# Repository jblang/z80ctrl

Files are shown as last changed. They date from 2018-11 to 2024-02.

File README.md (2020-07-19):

# z80ctrl

z80ctrl is an AVR-based bootloader, debugger, and I/O device for a Z80 retrocomputer with the following features:

- Plug-in module for [RC2014](https://rc2014.co.uk/) retrocomputer replaces the clock, serial, ROM, and CF boards
- Runs CP/M software directly from FAT32-formatted SD Card
- Boots unmodified disk images from the [AltairZ80](https://schorn.ch/altair.html) emulator
- Monitor with file management, memory inspector, and built-in Z80 disassembler
- Single-step debugging, breakpoints, and watchpoints to trace Z80 bus activity in real-time
- Expandable SPI bus allows bridging other SPI peripherals to the Z80
- Flexible MIT-licensed firmware can be the basis of your own SBC or breadboard computer

IMAGE ALT TEXT HERE (https://www.youtube.com/watch?v=sVV1PYWX18A)

## Documentation

Much of the information that was previously here has been moved to separate wiki pages:

- [Board Assembly Instructions](https://github.com/jblang/z80ctrl/wiki/Board-Assembly-Instructions)
- [Monitor User Guide](https://github.com/jblang/z80ctrl/wiki/Monitor-User-Guide)
- [Known Issues](https://github.com/jblang/z80ctrl/wiki/Known-Issues)
- [Hardware Design Notes](https://github.com/jblang/z80ctrl/wiki/Hardware-Design-Notes)
- [Software Design Notes](https://github.com/jblang/z80ctrl/wiki/Software-Design-Notes)
- [IO Expander Board](https://github.com/jblang/z80ctrl/wiki/IO-Expander-Board)
- Check the [Wiki Index](https://github.com/jblang/z80ctrl/wiki) for other topics.

## Off-Site Resources

- [Hackaday Project Page](https://hackaday.io/project/158338-z80ctrl) with blog articles about various features.
- [YouTube Playlist](https://www.youtube.com/watch?v=M8EIAxMpA-o&list=PLwP_dSEH4Oi_jAljWQ1H-TBiBL34LqYYm)
- [RC2014 Google Group](https://groups.google.com/forum/#!forum/rc2014-z80). Search for z80ctrl to find previous discussion threads.
- [retro-comp Google Group](https://groups.google.com/g/retro-comp)

## License

Copyright 2018-2020 J.B. Langston

Permission is hereby granted, free of charge, to any person obtaining a copy of this software and associated documentation files (the "Software"), to deal in the Software without restriction, including without limitation the rights to use, copy, modify, merge, publish, distribute, sublicense, and/or sell copies of the Software, and to permit persons to whom the Software is furnished to do so, subject to the following conditions:

The above copyright notice and this permission notice shall be included in all copies or substantial portions of the Software.

THE SOFTWARE IS PROVIDED "AS IS", WITHOUT WARRANTY OF ANY KIND, EXPRESS OR IMPLIED, INCLUDING BUT NOT LIMITED TO THE WARRANTIES OF MERCHANTABILITY, FITNESS FOR A PARTICULAR PURPOSE AND NONINFRINGEMENT. IN NO EVENT SHALL THE AUTHORS OR COPYRIGHT HOLDERS BE LIABLE FOR ANY CLAIM, DAMAGES OR OTHER LIABILITY, WHETHER IN AN ACTION OF CONTRACT, TORT OR OTHERWISE, ARISING FROM, OUT OF OR IN CONNECTION WITH THE SOFTWARE OR THE USE OR OTHER DEALINGS IN THE SOFTWARE.

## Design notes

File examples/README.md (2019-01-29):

# z80ctrl Example Programs

These are some example programs that demonstrate features of the z80ctrl and the I/O expander add-on card.

## Assembling

I have tried to stick to a common subset of assembler features that will work with any of the following cross-assemblers:

- [Sjasm](http://www.xl2s.tk/): Windows binaries available for download.  Compiles on Linux using sources on [Github](https://github.com/Konamiman/Sjasm).
- [SjasmPlus](https://sourceforge.net/projects/sjasmplus/):  Windows binaries available for download.  Compiles on Linux using sources on [Github](https://github.com/sjasmplus/sjasmplus).
- [z80asm](https://www.nongnu.org/z80asm/): Binaries available in the Debian repository. Mac binaries on [Homebrew](https://brew.sh/). Compiles on Windows.
- [z88dk](https://github.com/z88dk/z88dk)'s z80asm (not to be confused with above). Windows and Mac binaries available for download. Compiles on Linux.
- [pasmo](http://pasmo.speccy.org/): Windows and Mac binaries available for download. Binaries available in the Debain repository.

My preferred assembler is sjasm. I try to maintain compatibility with all of the above, but may not always test every change against the others.  If you have trouble assembling with any of the above, please try sjasm, and file a bug to let me know about the problem.

## About the Programs

- `graphclk.bas`: MSX-BASIC program draws a graphical clock on TMS9918A with time read from RTC.
- `hello.asm`: Simple hello world assembly program that uses the Altair UART emulation.
- `ioxblink.bas` MBASIC program that blinks an LED using the I/O expander.
- `lcd.bas`: MBASIC program that prompts for a string and prints it on an LCD hooked up to the I/O expander.
- `lcdclock.asm`: Assembly program that reads date/time from RTC and displays it on an LCD hooked up to the I/O expander.
- `rtc.bas`: MBASIC program that reads the date/time from RTC and prints it on the console.
- `z80ops.asm`: Assembly program with all Z80 opcodes, for testing disassembler.

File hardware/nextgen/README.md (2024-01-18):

## z80ctrl NG

**Important: This design has not yet been tested.  Manufacture at your own risk.**

This is a new design for z80ctrl using the [Microchip AVR128DB64](https://www.microchip.com/en-us/product/avr128db64) microcontroller. 

This next-gen AVR has several advantages over the ATmega1284P used in the original design:

- It's a 64-pin part with more than enough I/O to interface with the RC2014 bus without an I/O expander. This will allow much faster data transfers since all signals are accessed in parallel rather than serially.
- It has built-in configurable logic used to assert the wait signal on I/O requests without external glue logic.
- It has multi-voltage I/O where one port can run at 3.3V to interface the SD card and other peripherals directly without level shifters.
- It has UPDI single-wire programming and debug interface, so it's possible to actually use the debugger in MPLAB X with a PicKit, without sacrificing too many pins to JTAG. UPDI also allows the part to be programmed directly from the USB to serial converter without a bootloader.
- The TQFP package leaves enough space to incorporate 512KB of RAM with optional bank switching and an RTC on the same board.
- The one disadvantage is that it's a fine-pitched surface mount part, but now that PCB manufacturers offer board assembly service, it is possible to order a board with the surface mount components pre-populated.

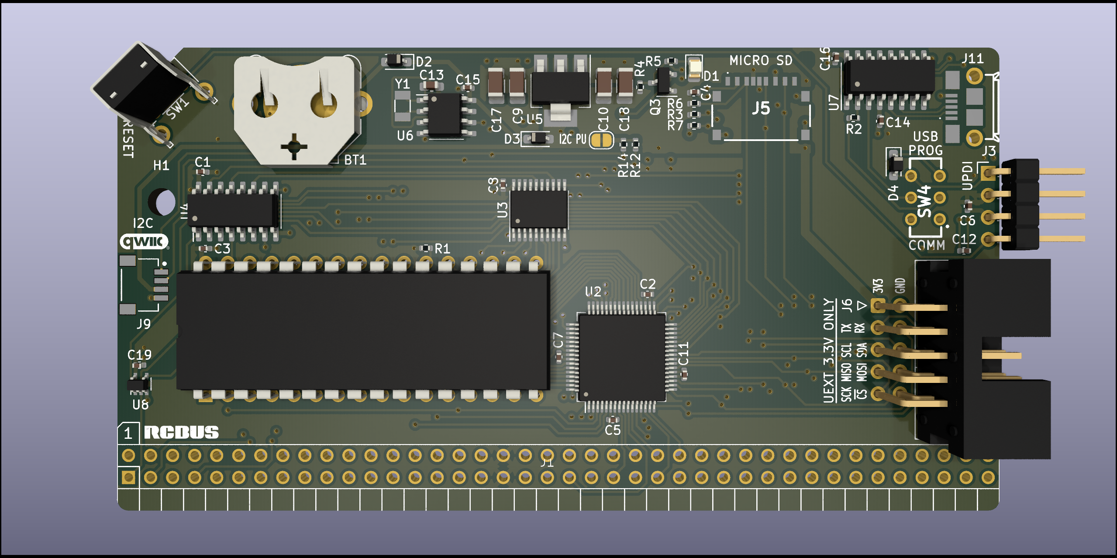
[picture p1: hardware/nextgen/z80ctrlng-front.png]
Front Render


### RAM

This board combines features of the original z80ctrl board plus the RAM and RTC from the companion CPU/RAM/RTC board. The CPU remains on a separate board so that z80ctrl can be used with different CPUs.  

The RAM uses the same bank switching scheme as the original board, with two 32K windows into 512K of RAM:
- The active banks for the upper and lower windows are stored in the upper and lower nybbles of a 74HCT574 8-bit register.  
- A 74HCT257 multiplexer selects between the two windows based on state of A15.  
- Bank switching on this board can be disabled via the slide switch, in which case A15 is connected directly to the SRAM and the output of the 74HCT257 is disabled.  
- A16-A18 are connected directly to the bus, so with bank switching disabled, a CPU with more address lines can be used. 
- The AVR is connected to A16-A18 directly as well so it can work with all 512KB of RAM in either mode.
- Instead of using a 74HCT138 decoder to bank register, it is controlled directly by the AVR. The AVR will listen on a configurable I/O port for bank changes from the CPU and update the flip-flop as needed.

The RAM and bank logic chips are still DIPs to keep the retro vibe, and for practical reasons as well:
- It should still be possible to use z80ctrl for SBCs like the SC126, which already has RAM and ROM, by leaving the RAM on the z80ctrl unpopulated.
- Choosing not to populate the RAM and logic chips allows using the z80ctrl as a stand-alone AVR dev board.
  - Without these chips populated, all the pins used for A0-A18 and D0-D7, and the Z80 control singals can used as GPIO.
  - The passive RCBus backplane can be used to connect non-retro components over the bus.

### MicroSD Card

The board incorporates a MicroSD card holder that the AVR controls over SPI on its 3.3V port.

### RTC

The board includes an RTC for accurate timestamps on the files stored on the SD card:

- The chip used is an [NXP PCF8563T](https://www.nxp.com/part/PCF8563T) I2C RTC. It is backed up by a CR1216 coin cell.
- The bus can be shared with additional I2C peripherals as long as they do not use the same address as the RTC.

### USB Adapter

An on-board [CH340C](https://cdn.sparkfun.com/assets/9/3/0/2/e/ch3402CDS.pdf) USB-to-Serial adapter allows connecting the z80ctrl directly to a host computer over a MicroUSB cable, without any external USB-to-Serial converter required.

Using the PROG EN slide switch, it's also possible to enable programming of the chip via UPDI without a bootloader installed using the same USB connection used for serial communication.

### UEXT Bus

- The 3-volt SPI, I2C, and UART signals are exposed on the [UEXT header](https://www.olimex.com/Products/Modules/UEXT/). This allows it to interface with many different 3V peripherals using I2C, UART, or SPI. 
- Olimex sells many modules using the UEXT connector. For example, a $4 [ESP8266 module](https://www.olimex.com/Products/IoT/ESP8266/MOD-WIFI-ESP8266/open-source-hardware) will allow the z80ctrl to access the internet over its UART using the [ESP AT](https://github.com/espressif/esp-at) firmware.
- The AVR can expose an parallel interface to peripherals over I/O requests on the RCbus.

### Optional RCBus Connections

- The second 5V UART can be connected or disconnected from RX1 or RX2 and TX1 or TX2 signals on the RCbus using jumpers on the serial header.
- 3.3V SPI, I2C, and UART signals can be optionally exported onto the D8-D15 pins by creating a solder bridge on the corresponding surface mount jumpers.

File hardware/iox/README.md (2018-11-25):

[See Wiki](https://github.com/jblang/z80ctrl/wiki/IO-Expander-Board)

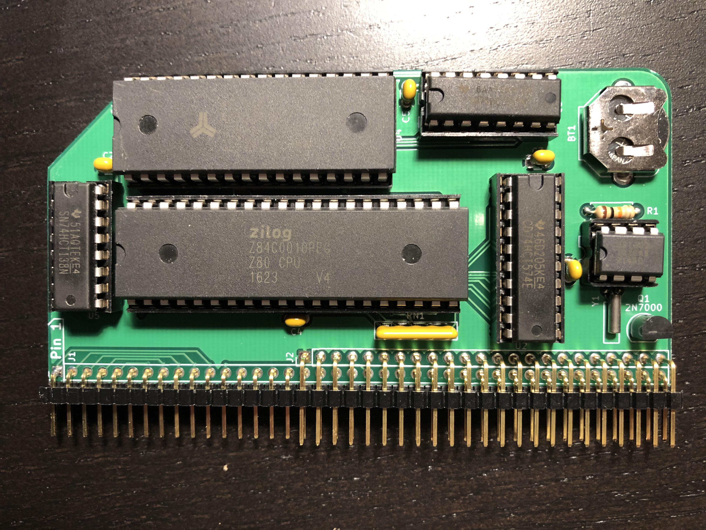
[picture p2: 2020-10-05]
hardware/z80ram/board.jpg

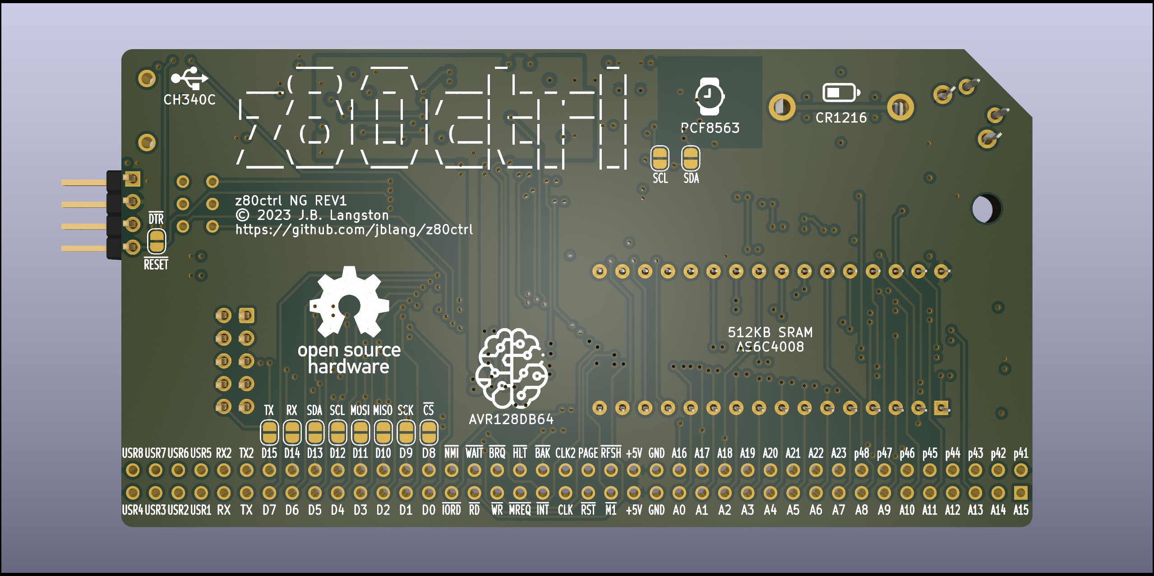
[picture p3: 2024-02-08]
hardware/nextgen/z80ctrlng-back.png

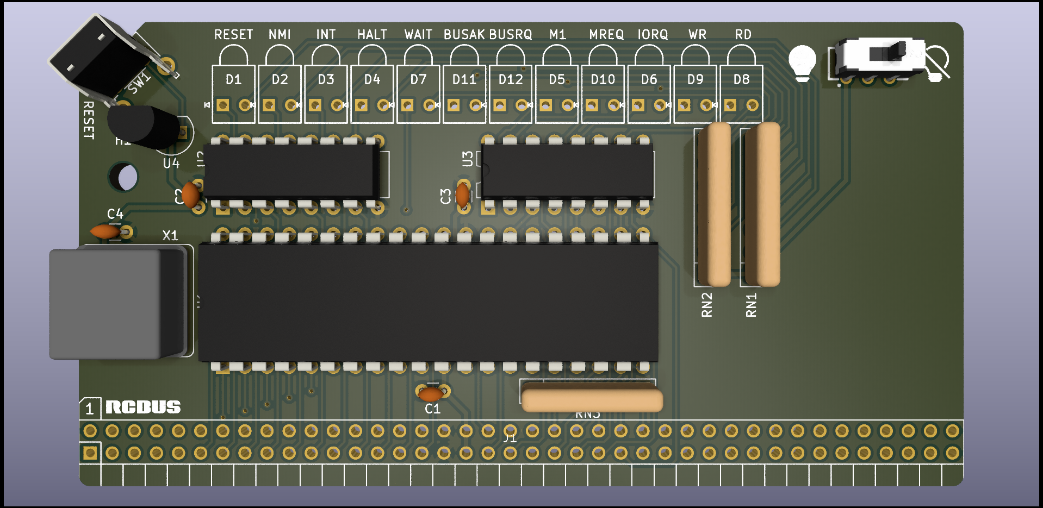
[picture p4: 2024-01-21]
hardware/z80blinken/z80blinken-front.png

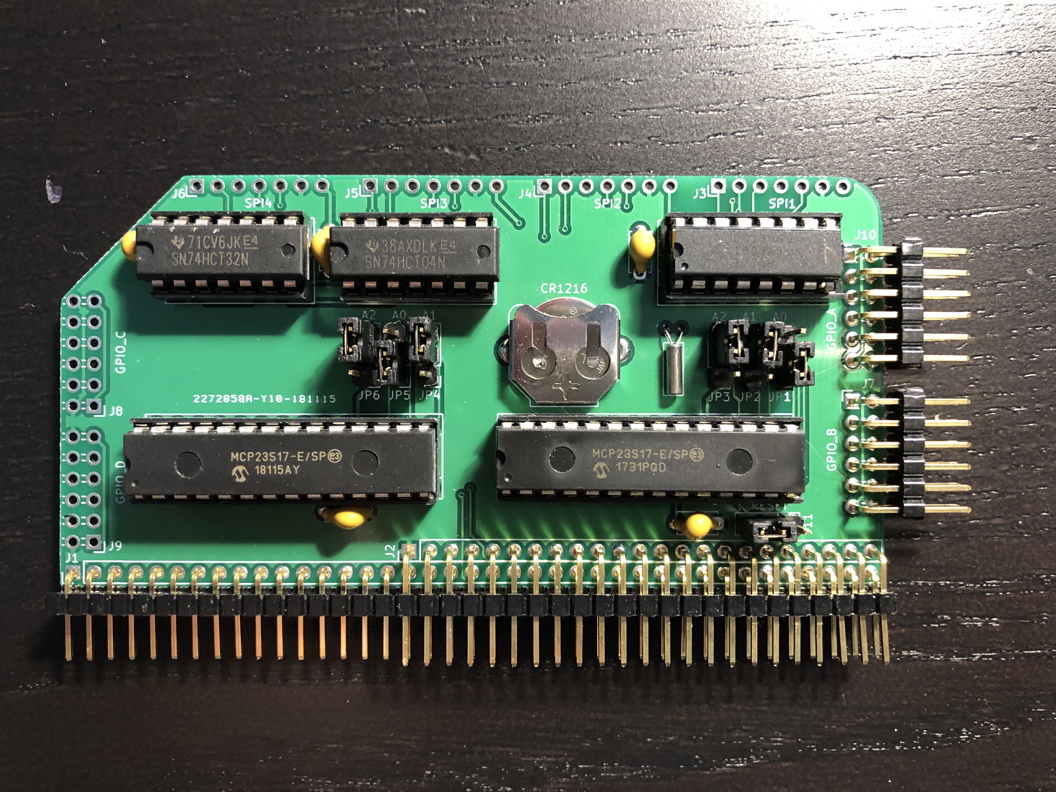
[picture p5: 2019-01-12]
hardware/iox/board.jpg

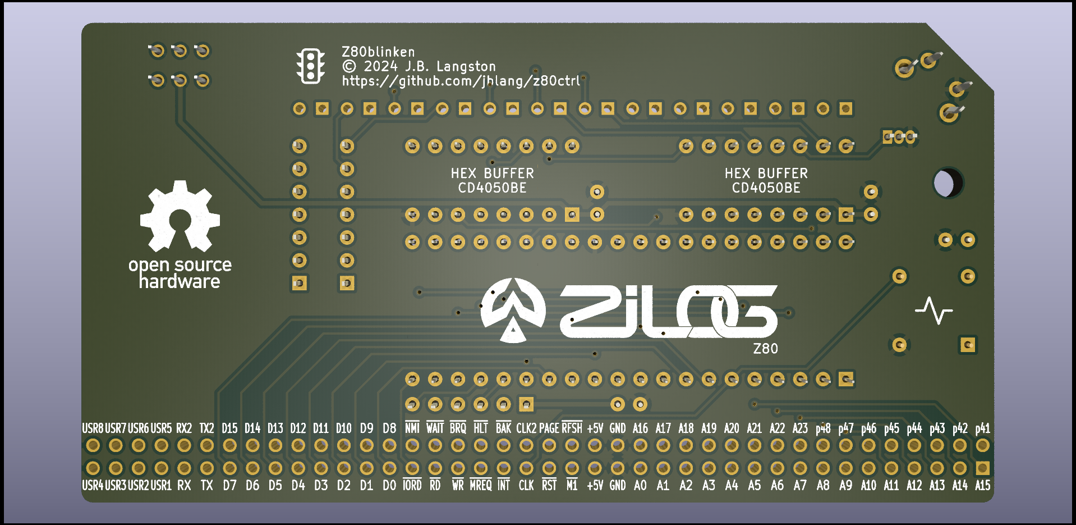
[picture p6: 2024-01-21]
hardware/z80blinken/z80blinken-back.png

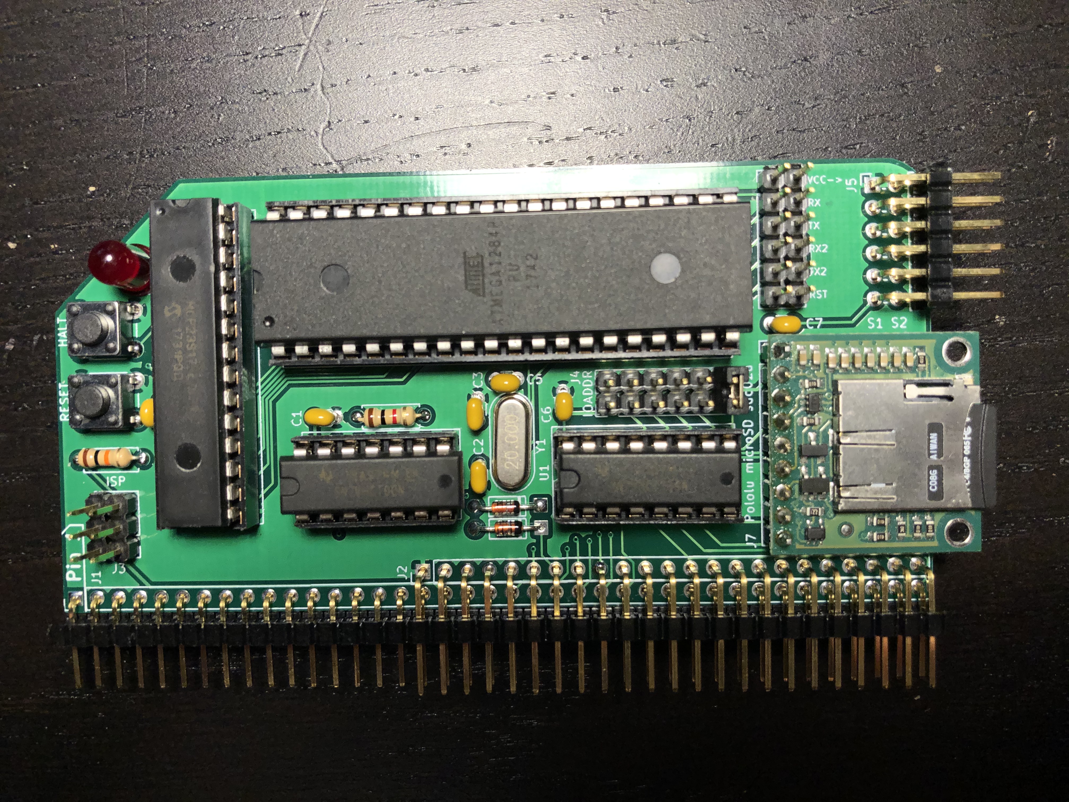
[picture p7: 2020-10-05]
board.jpg

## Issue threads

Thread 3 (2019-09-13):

Problem loading hello.hex

tmator, 2019-09-13:
Hi,

i'm trying to load hello.hex but it's not working, i got :

z80ctrl:/>loadhex hello.hex
loading from hello.hex
bus master request timed out
loaded 45 bytes total from 0100-012c

Any idea ?

Regards.

tmator, 2019-09-13:
And i'm using SC114 motherboard, not RC2014

tmator, 2019-09-13:
Ok, need enchanced bus ! sorry

tmator, 2019-09-13:
Error still here with after connexting nmi, halt, busak, wait, busrq and refsh (SC114 dont have enhanced bus), any idea ?

jblang, 2020-04-23:
I'm sorry, I hadn't worked on z80ctrl for a while and I didn't see that you submitted it. Did you ever figure it out?

I would suggest using a logic analyzer or oscilloscope to see if the busrq and busak lines are actually going low as expected.  Check the busrq signal on the CPU board and the busak signal on the z80ctrl board to make sure the signals are getting from one board to another.   Also make sure that the clock signal is getting to the Z80 from the z80ctrl, and make sure you don't have any other clock sources on the bus.  Make sure that the CLK/WAIT jumper is in the CLK position. A multimeter might do in a pinch but the signals are usually too fast for it to detect so you'd need to edit the code and put in a delay in the correct spots. Some multimeters also have a frequency measurement that you could use to check the clock.

If you're not getting the appropriate signals, check that there are no shorts that are pulling the line up. Visually check for solder bridges and check for continuity between adjacent pins on the bus connector and chips.

jblang, 2020-06-13:
Closing this since I never heard back from you.

Closed 2020-06-13.

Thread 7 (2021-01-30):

where is the J9  description in REV4 and REV6 ?

wenij, 2021-01-30:
I check the "Board Assembly instruction/Jumper configuration" in wiki. And in REV6, it say "J9 (CLK/WAIT) jumper ... ", but I can't find the J9 in the PCB or schematic. Where can I find it?

jblang, 2021-02-04:
There is no CLK/WAIT jumper in REV6.  On REV4 it should always be set to CLK

jblang, 2021-02-04:
It was a copy/paste error that it was listed under REV6. I removed it.

Closed 2021-02-04.

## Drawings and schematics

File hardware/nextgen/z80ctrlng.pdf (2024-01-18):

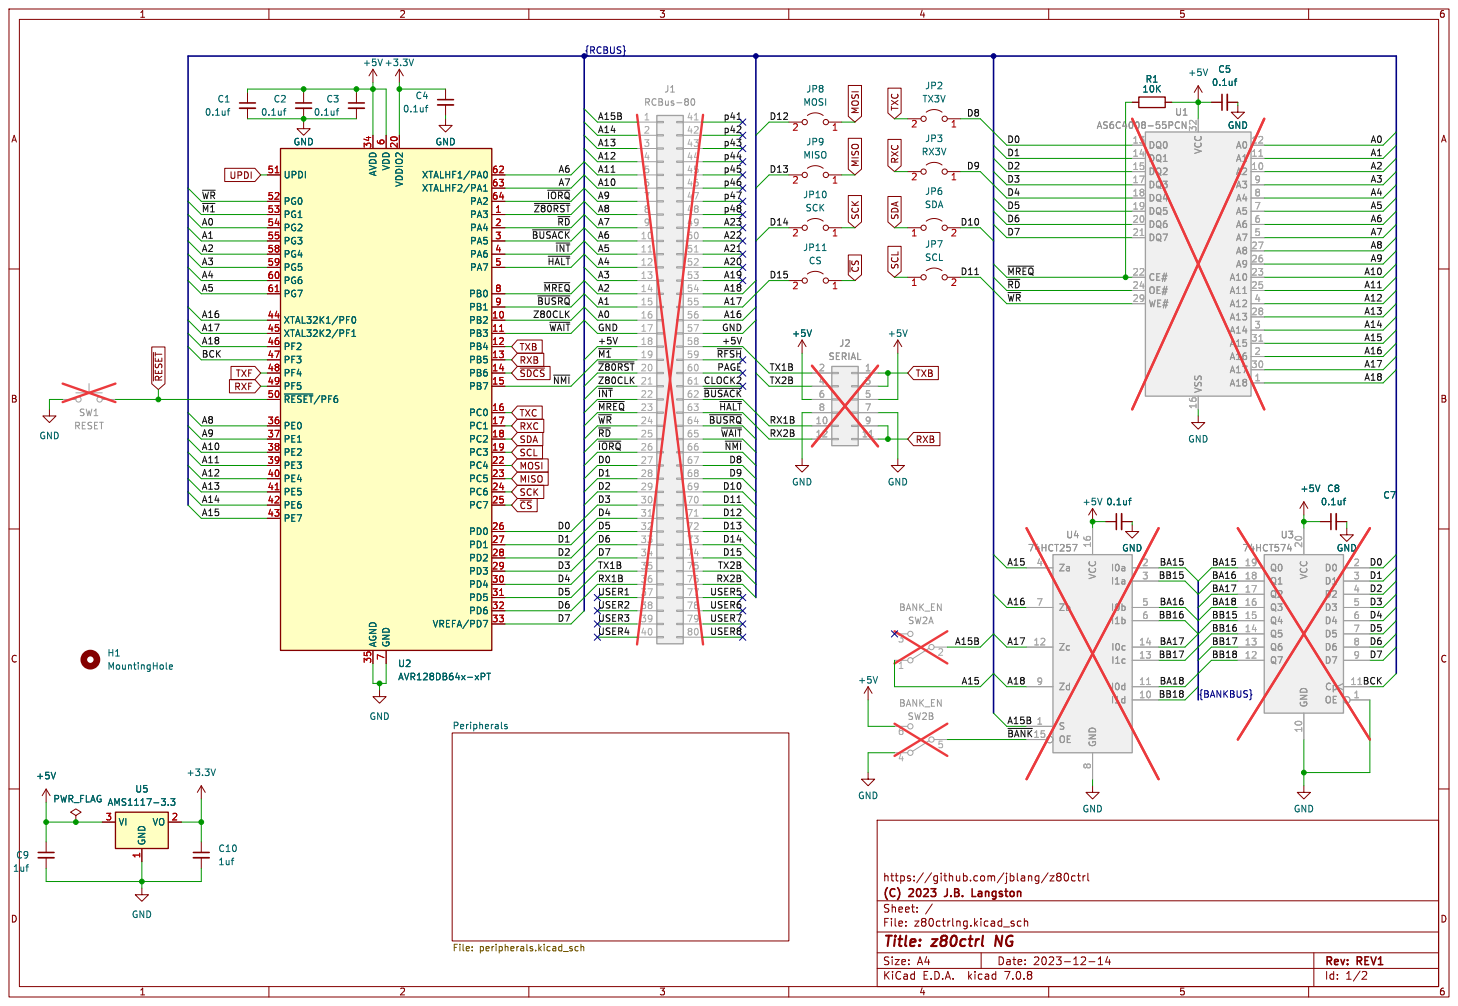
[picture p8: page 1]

TXC
RXC
SCL MOSI SDA MISO

https://github.com/jblang/z80ctrl

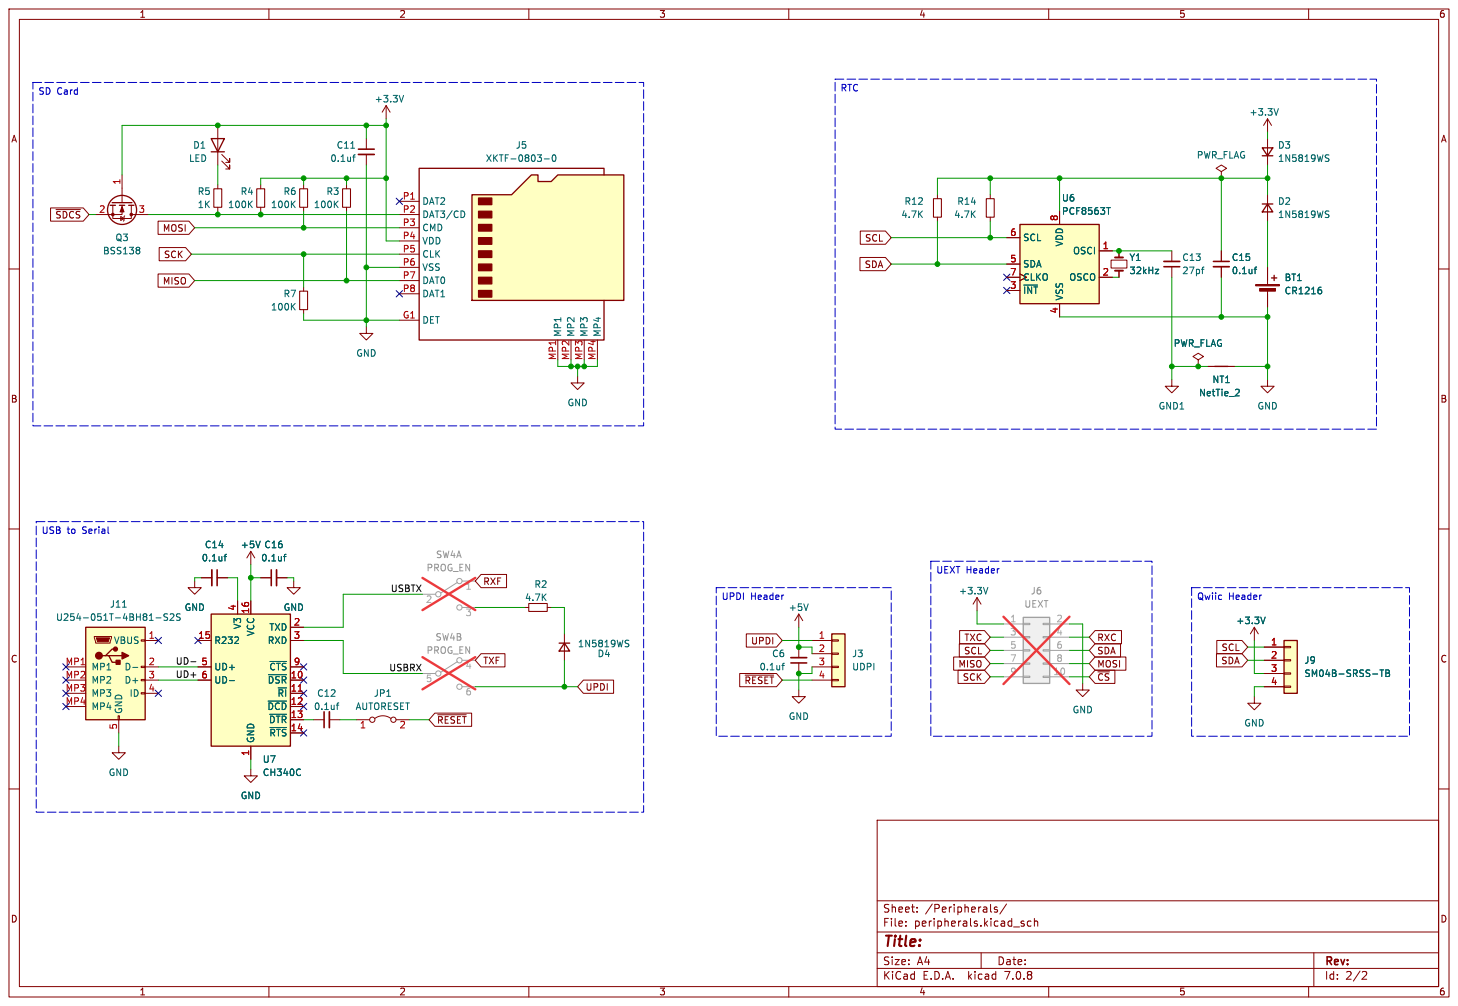
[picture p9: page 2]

SDA UPDI MISO MOSI SCK

4 SDA 5 SCL 6 CLKO 7 VDD

1 ~{DSR} 10 ~{RI} 11 ~{DCD} 12 ~{DTR} 13 ~{RTS} 14 R232 15 VCC 16 TXD 2 RXD 3 V3

4 UD+ 5 UD- 6 ~{CTS}9 GND

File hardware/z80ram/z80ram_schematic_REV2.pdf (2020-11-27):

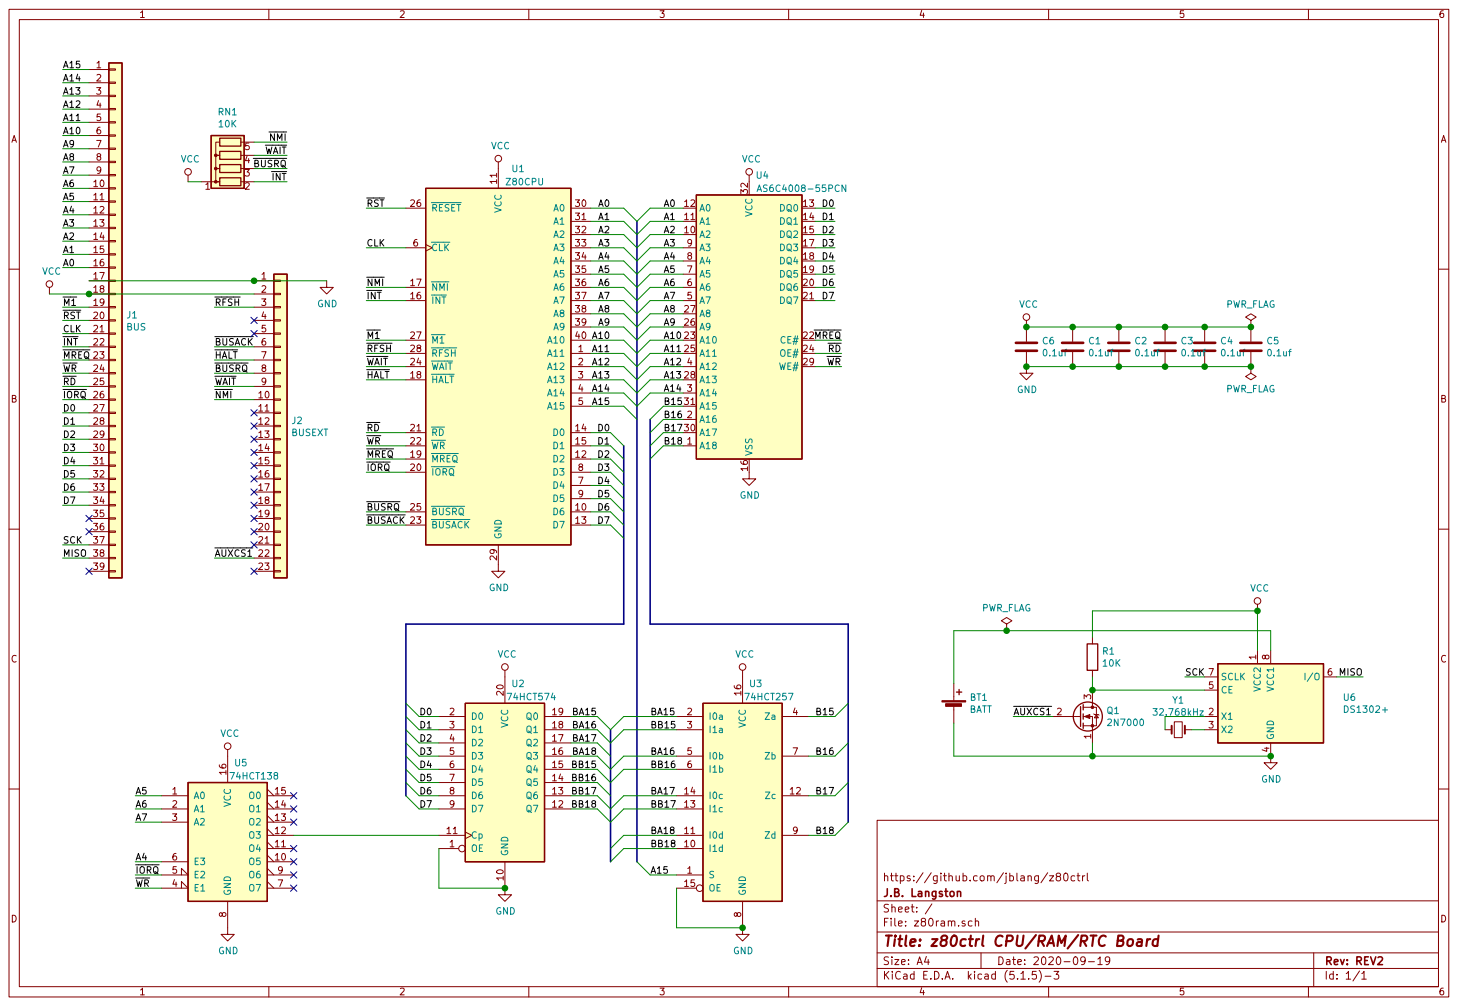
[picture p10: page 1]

INT NMI WAIT BUSRQ

File: z80ram.sch Sheet: / J.B. Langston

Id: 1/1 Title: z80ctrl CPU/RAM/RTC Board

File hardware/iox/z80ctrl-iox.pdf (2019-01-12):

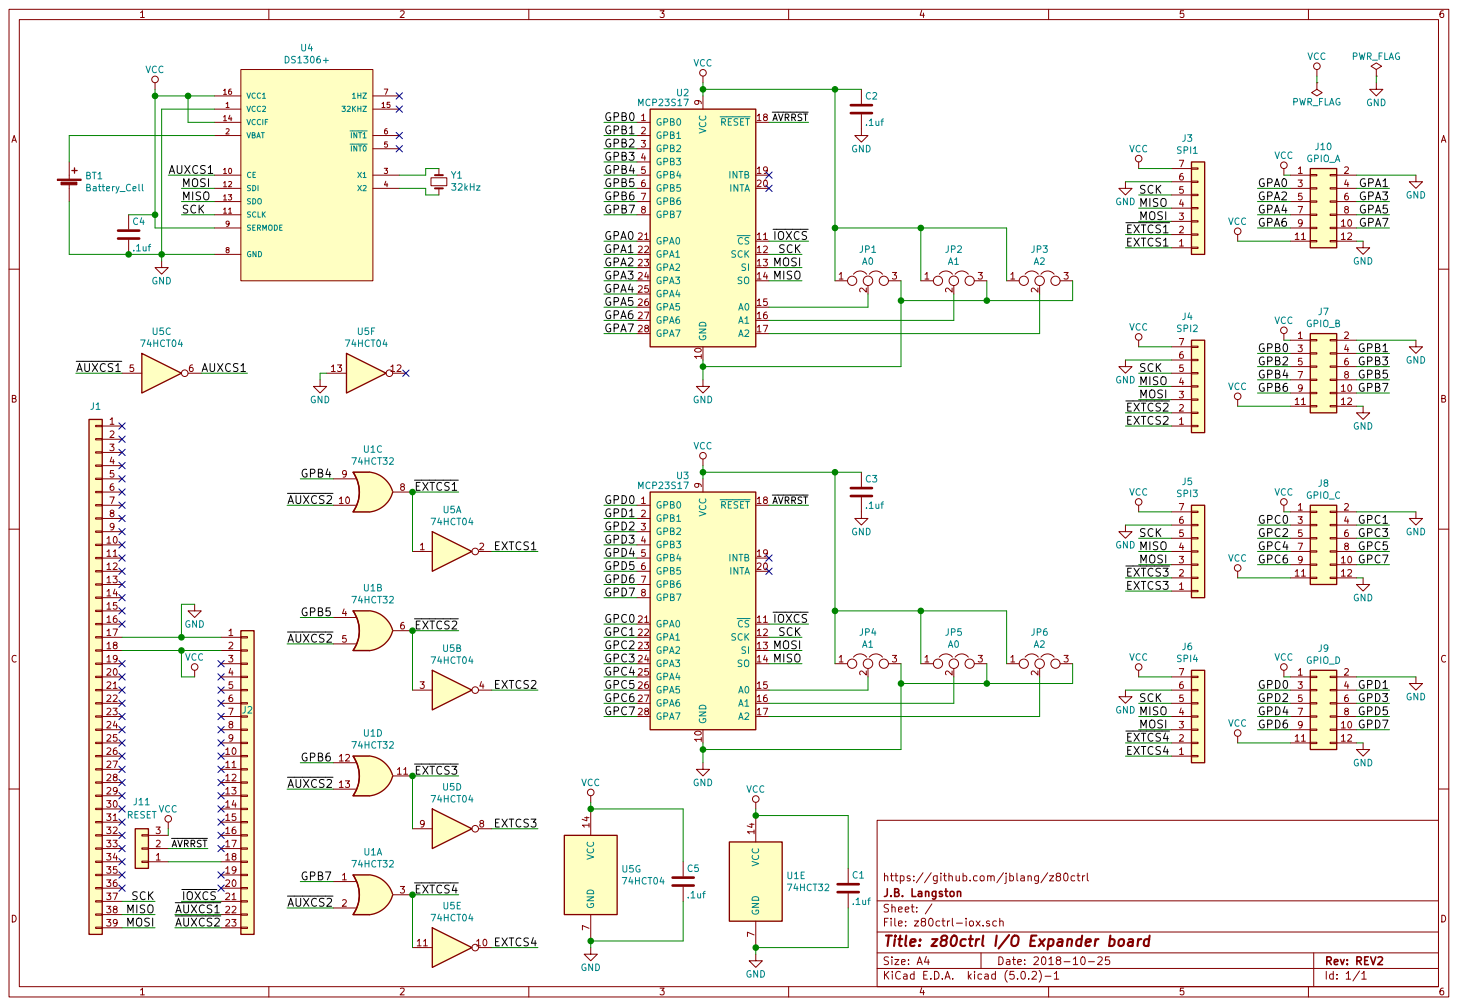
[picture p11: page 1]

https://github.com/jblang/z80ctrl
File: z80ctrl-iox.sch Sheet: / J.B. Langston
Id: 1/1 Title: z80ctrl I/O Expander board

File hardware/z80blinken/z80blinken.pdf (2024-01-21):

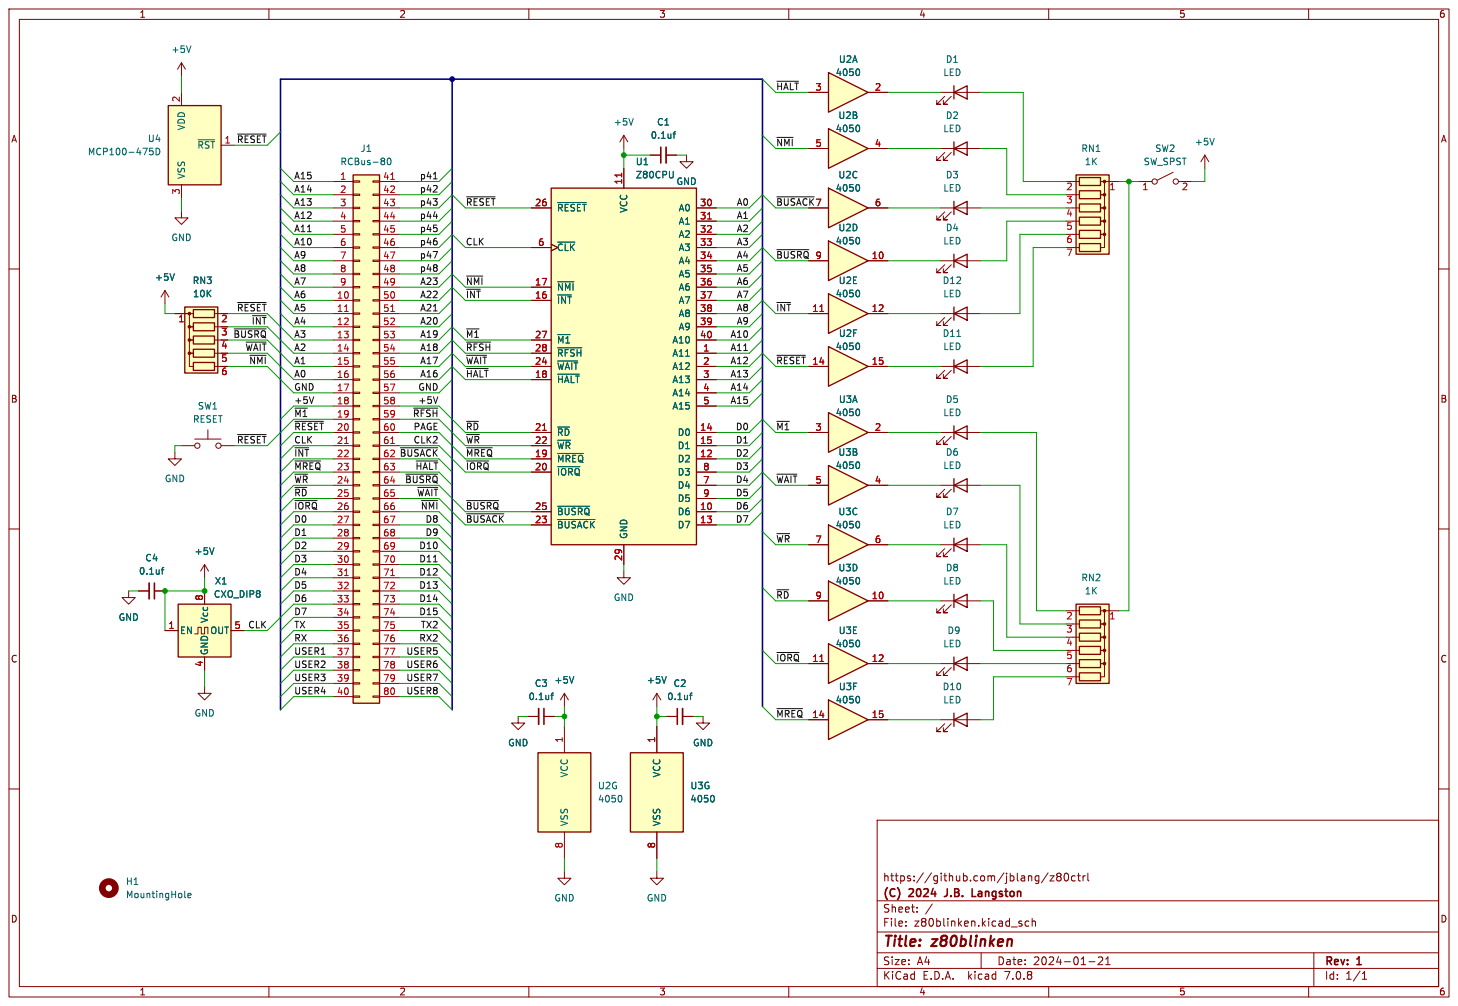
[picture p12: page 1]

https://github.com/jblang/z80ctrl

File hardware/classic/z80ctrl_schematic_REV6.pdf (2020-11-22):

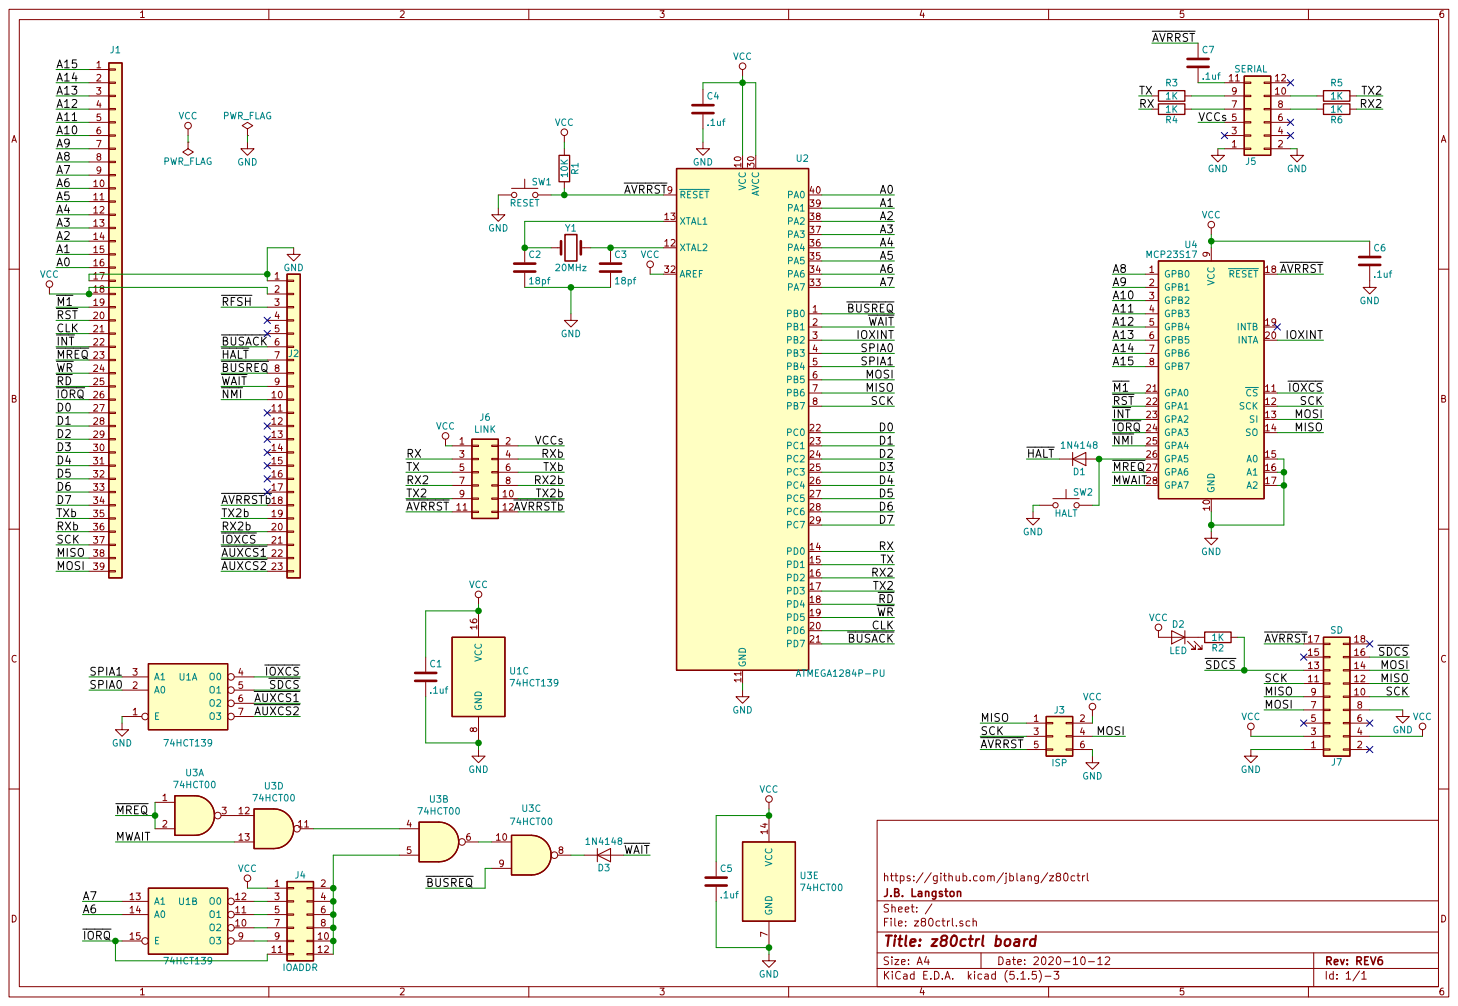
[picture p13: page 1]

20 | 4
21 | 5

9 | 10
11 | 12

38 | AUXCS1 22
39 | AUXCS2 23

https://github.com/jblang/z80ctrl
File: z80ctrl.sch Sheet: / J.B. Langston

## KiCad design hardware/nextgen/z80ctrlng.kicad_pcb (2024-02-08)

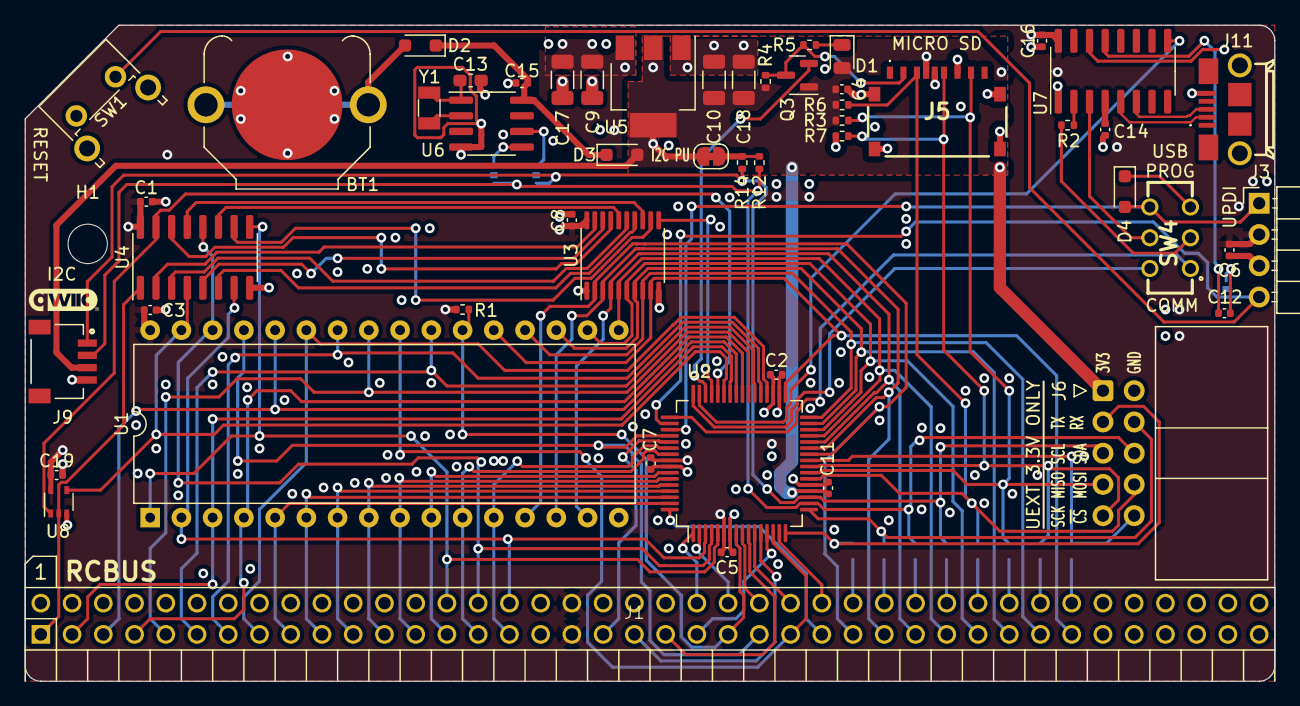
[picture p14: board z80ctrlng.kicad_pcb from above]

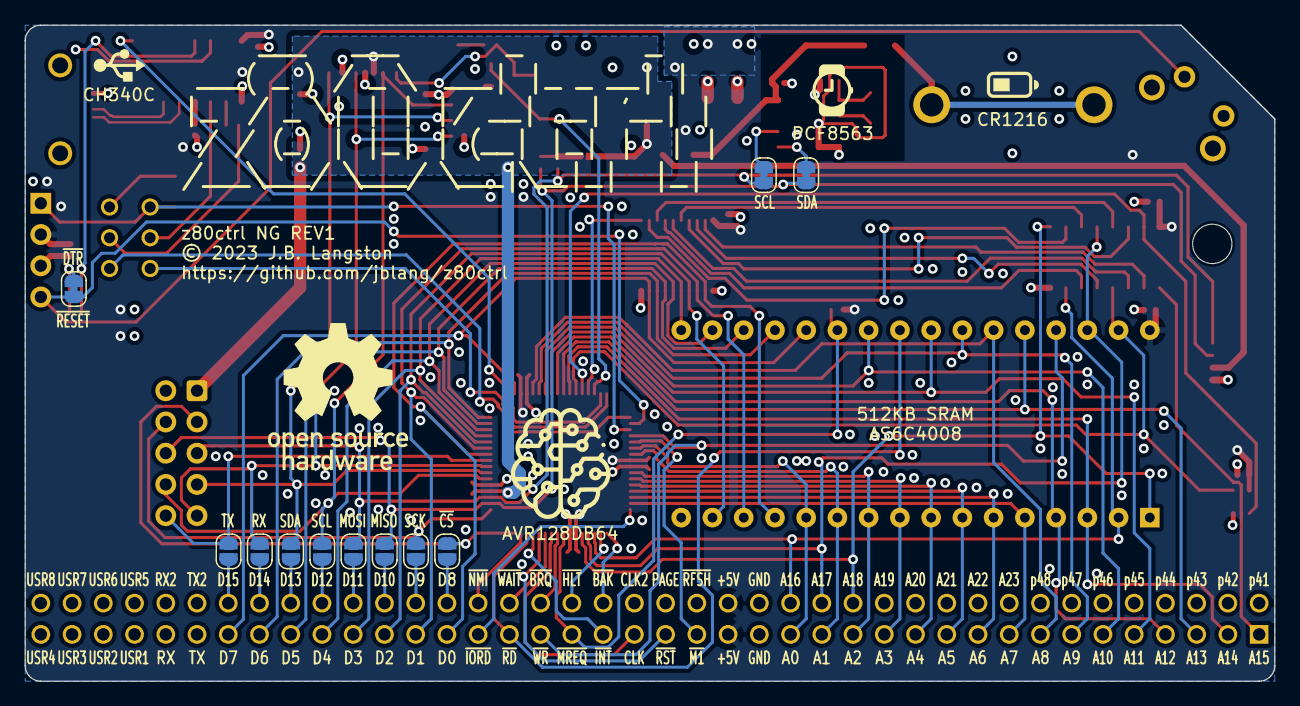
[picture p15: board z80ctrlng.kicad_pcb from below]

Board: 4 copper layers, 101.6 x 53.3 mm, 65 parts (11 on the bottom side), 95 nets.

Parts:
BT1: CR1216; BatteryHolder_Keystone_3001_1x12mm
C1, C2, C3, C4, C5, C6, C7, C8, C11, C12, C14, C15, C16, C19: 0.1uf; C_0402_1005Metric
C9, C10: 1uf; C_1206_3216Metric
C13: 27pf; C_0603_1608Metric_Pad1.08x0.95mm_HandSolder
C17, C18: 22uf; C_1206_3216Metric
D1: LED; LED_0805_2012Metric
D2, D3, D4: 1N5819WS; D_SOD-323_HandSoldering
H1: MountingHole; MountingHole_3.2mm_M3
J1: RCBUS; RCBus-80
J3: UDPI; PinHeader_1x04_P2.54mm_Horizontal
J5: XKTF-0803-0; XKTF08030
J6: UEXT; IDC-Header_2x05_P2.54mm_Horizontal
J9: SM04B-SRSS-TB; JST_SM04B-SRSS-TB_LF__SN_
J11: U254-051T-4BH81-S2S; U254051T4BH81S2S
JP1: AUTORESET; SolderJumper-2_P1.3mm_Bridged_RoundedPad1.0x1.5mm
JP2: TX3V; SolderJumper-2_P1.3mm_Open_RoundedPad1.0x1.5mm
JP3: RX3V; SolderJumper-2_P1.3mm_Open_RoundedPad1.0x1.5mm
JP6: SDA; SolderJumper-2_P1.3mm_Open_RoundedPad1.0x1.5mm
JP7: SCL; SolderJumper-2_P1.3mm_Open_RoundedPad1.0x1.5mm
JP8: MOSI; SolderJumper-2_P1.3mm_Open_RoundedPad1.0x1.5mm
JP9: MISO; SolderJumper-2_P1.3mm_Open_RoundedPad1.0x1.5mm
JP10: SCK; SolderJumper-2_P1.3mm_Open_RoundedPad1.0x1.5mm
JP11: CS; SolderJumper-2_P1.3mm_Open_RoundedPad1.0x1.5mm
JP13: RTC_SCL; SolderJumper-2_P1.3mm_Bridged_RoundedPad1.0x1.5mm
JP15: RTC_SDA; SolderJumper-2_P1.3mm_Bridged_RoundedPad1.0x1.5mm
JP16: I2C_PU; SolderJumper-2_P1.3mm_Bridged_RoundedPad1.0x1.5mm
NT1: NetTie_2; NetTie-2_SMD_Pad0.5mm
Q3: BSS138; SOT-23
R1: 10K; R_0402_1005Metric
R2, R5: 1K; R_0402_1005Metric
R3, R4, R6, R7: 100K; R_0402_1005Metric
R12, R14: 2.2K; R_0402_1005Metric
SW1: RESET; SW_Tactile_SPST_Angled_PTS645Vx31-2LFS
SW4: PROG_EN; JS202011CQN
U1: AS6C4008-55PCN; DIP-32_W15.24mm
U2: AVR128DB64x-xPT; TQFP-64_10x10mm_P0.5mm
U3: 74HCT573; TSSOP-20_4.4x6.5mm_P0.65mm
U4: 74HCT257; SOIC-16_3.9x9.9mm_P1.27mm
U5: AMS1117-3.3; SOT-223-3_TabPin2
U6: PCF8563T; SOIC-8_3.9x4.9mm_P1.27mm
U7: CH340C; SOIC-16_3.9x9.9mm_P1.27mm
U8: 74LVC1G126; SOT-353_SC-70-5
Y1: 32kHz; Crystal_SMD_3215-2Pin_3.2x1.5mm

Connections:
+3.3V: C4.1, C10.1, C11.1, C18.1, D1.2 (A), D3.2 (A), J5.P4 (VDD), J6.1, J9.3, JP16.2 (B), Q3.1 (G), R3.1, R4.1, R6.1, U2.20 (VDDIO2), U5.2 (VO)
+5V: C1.1, C2.1, C3.1, C5.1, C6.2, C7.1, C8.1, C9.1, C16.1, C17.1, C19.1, J1.18, J1.58, J3.2, R1.2, U1.32 (VCC), U2.6 (VDD), U2.34 (AVDD), U2.56 (VDD), U3.20 (VCC), U4.16 (VCC), U5.3 (VI), U7.16 (VCC), U8.5 (VCC)
/A0: J1.16, U1.12 (A0), U2.54 (PG2)
/A1: J1.15, U1.11 (A1), U2.55 (PG3)
/A2: J1.14, U1.10 (A2), U2.58 (PG4)
/A3: J1.13, U1.9 (A3), U2.59 (PG5)
/A4: J1.12, U1.8 (A4), U2.60 (PG6)
/A5: J1.11, U1.7 (A5), U2.61 (PG7)
/A6: J1.10, U1.6 (A6), U2.62 (XTALHF1/PA0)
/A7: J1.9, U1.5 (A7), U2.63 (XTALHF2/PA1)
/A8: J1.8, U1.27 (A8), U2.36 (PE0)
/A9: J1.7, U1.26 (A9), U2.37 (PE1)
/A10: J1.6, U1.23 (A10), U2.38 (PE2)
/A11: J1.5, U1.25 (A11), U2.39 (PE3)
/A12: J1.4, U1.4 (A12), U2.40 (PE4)
/A13: J1.3, U1.28 (A13), U2.41 (PE5)
/A14: J1.2, U1.3 (A14), U2.42 (PE6)
/A15: U1.31 (A15), U2.43 (PE7), U4.4 (Za), U8.4
/A15B: J1.1, U4.1 (S), U8.2
/A16: J1.56, U1.2 (A16), U2.3 (PA5), U4.7 (Zb)
/A17: J1.55, U1.30 (A17), U2.4 (PA6), U4.12 (Zc)
/A18: J1.54, U1.1 (A18), U2.5 (PA7), U4.9 (Zd)
/BA15: U3.19 (Q0), U4.2 (I0a)
/BA16: U3.18 (Q1), U4.5 (I0b)
/BA17: U3.17 (Q2), U4.14 (I0c)
/BA18: U3.16 (Q3), U4.11 (I0d)
/BB15: U3.15 (Q4), U4.3 (I1a)
/BB16: U3.14 (Q5), U4.6 (I1b)
/BB17: U3.13 (Q6), U4.13 (I1c)
/BB18: U3.12 (Q7), U4.10 (I1d)
/BLAT: U2.45 (XTAL32K2/PF1), U3.11 (Load)
/D0: J1.27, U1.13 (DQ0), U2.26 (PD0), U3.2 (D0)
/D1: J1.28, U1.14 (DQ1), U2.27 (PD1), U3.3 (D1)
/D2: J1.29, U1.15 (DQ2), U2.28 (PD2), U3.4 (D2)
/D3: J1.30, U1.17 (DQ3), U2.29 (PD3), U3.5 (D3)
/D4: J1.31, U1.18 (DQ4), U2.30 (PD4), U3.6 (D4)
/D5: J1.32, U1.19 (DQ5), U2.31 (PD5), U3.7 (D5)
/D6: J1.33, U1.20 (DQ6), U2.32 (PD6), U3.8 (D6)
/D7: J1.34, U1.21 (DQ7), U2.33 (VREFA/PD7), U3.9 (D7)
/D8: J1.67, JP2.1 (A)
/D9: J1.68, JP3.1 (A)
/D10: J1.69, JP6.2 (B)
/D11: J1.70, JP7.2 (B)
/D12: J1.71, JP8.2 (B)
/D13: J1.72, JP9.2 (B)
/D14: J1.73, JP10.2 (B)
/D15: J1.74, JP11.2 (B)
/Peripherals/UD+: J11.3 (D+), U7.6 (UD-)
/Peripherals/UD-: J11.2 (D-), U7.5 (UD+)
/Peripherals/USBRX: SW4.5 (B), U7.3 (RXD)
/Peripherals/USBTX: R2.2, SW4.2 (B)
/Z80CLK: J1.21, U2.10 (PB2)
/~BANK: U2.44 (XTAL32K1/PF0), U4.15 (OE), U8.1
/~BUSACK: J1.62, U2.1 (PA3)
/~BUSRQ: J1.64, U2.9 (PB1)
/~HALT: J1.63, U2.2 (PA4)
/~INT: J1.22, U2.13 (PB5)
/~IORQ: J1.26, U2.64 (PA2)
/~M1: J1.19, U2.53 (PG1)
/~MREQ: J1.23, R1.1, U1.22 (CE#), U2.8 (PB0)
/~NMI: J1.66, U2.15 (PB7)
/~RD: J1.25, U1.24 (OE#), U2.14 (PB6)
/~WAIT: J1.65, U2.11 (PB3)
/~WR: J1.24, U1.29 (WE#), U2.52 (PG0)
/~Z80RST: J1.20, U2.12 (PB4)
GND: BT1.2 (-), C1.2, C2.2, C3.2, C4.2, C5.2, C6.1, C7.2, C8.2, C9.2, C10.2, C11.2, C14.2, C15.2, C16.2, C17.2, C18.2, C19.2, J1.17, J1.57, J3.3, J5.G1 (DET), J5.MP1, J5.MP2, J5.MP3, J5.MP4, J5.P6 (VSS), J6.2, J9.4, J11.5 (GND), NT1.2, R7.1, SW1.1, U1.16 (VSS), U2.7 (GND), U2.21 (GND), U2.35 (AGND), U2.57 (GND), U3.1 (OE), U3.10 (GND), U4.8 (GND), U5.1 (GND), U6.4 (VSS), U7.1 (GND), U8.3 (GND)
GND1: C13.1, NT1.1
MISO: J5.P7 (DAT0), J6.7, JP9.1 (A), R3.2, U2.23 (PC5)
MOSI: J5.P3 (CMD), J6.8, JP8.1 (A), R6.2, U2.22 (PC4)
unnamed: BT1.1 (+), D2.2 (A)
unnamed: D1.1 (K), R5.2
unnamed: C15.1, D2.1 (K), D3.1 (K), U6.8 (VDD)
unnamed: D4.1 (K), SW4.3 (C)
unnamed: J5.P2 (DAT3/CD), Q3.3 (D), R4.2, R5.1
unnamed: C12.2, JP1.1 (A)
unnamed: JP13.2 (B), U6.6 (SCL)
unnamed: JP15.2 (B), U6.5 (SDA)
unnamed: JP16.1 (A), R12.1, R14.1
unnamed: C13.2, U6.1 (OSCI), Y1.2
unnamed: U6.2 (OSCO), Y1.1
unnamed: R2.1, U7.2 (TXD)
unnamed: C14.1, U7.4 (V3)
unnamed: C12.1, U7.13 (~DTR)
RXC: J6.4, JP3.2 (B), U2.17 (PC1)
RXF: SW4.1 (A), U2.49 (PF5)
SCK: J5.P5 (CLK), J6.9, JP10.1 (A), R7.2, U2.24 (PC6)
SCL: J6.5, J9.1, JP7.1 (A), JP13.1 (A), R14.2, U2.19 (PC3)
SDA: J6.6, J9.2, JP6.1 (A), JP15.1 (A), R12.2, U2.18 (PC2)
TXC: J6.3, JP2.2 (B), U2.16 (PC0)
TXF: SW4.4 (A), U2.48 (PF4)
UPDI: D4.2 (A), J3.1, SW4.6 (C), U2.51 (UPDI)
~CS: J6.10, JP11.1 (A), U2.25 (PC7)
~CTS: U2.47 (PF3), U7.9 (~CTS)
~RESET: J3.4, JP1.2 (B), SW1.2, U2.50 (~RESET/PF6)
~SDCS: Q3.2 (S), U2.46 (PF2)

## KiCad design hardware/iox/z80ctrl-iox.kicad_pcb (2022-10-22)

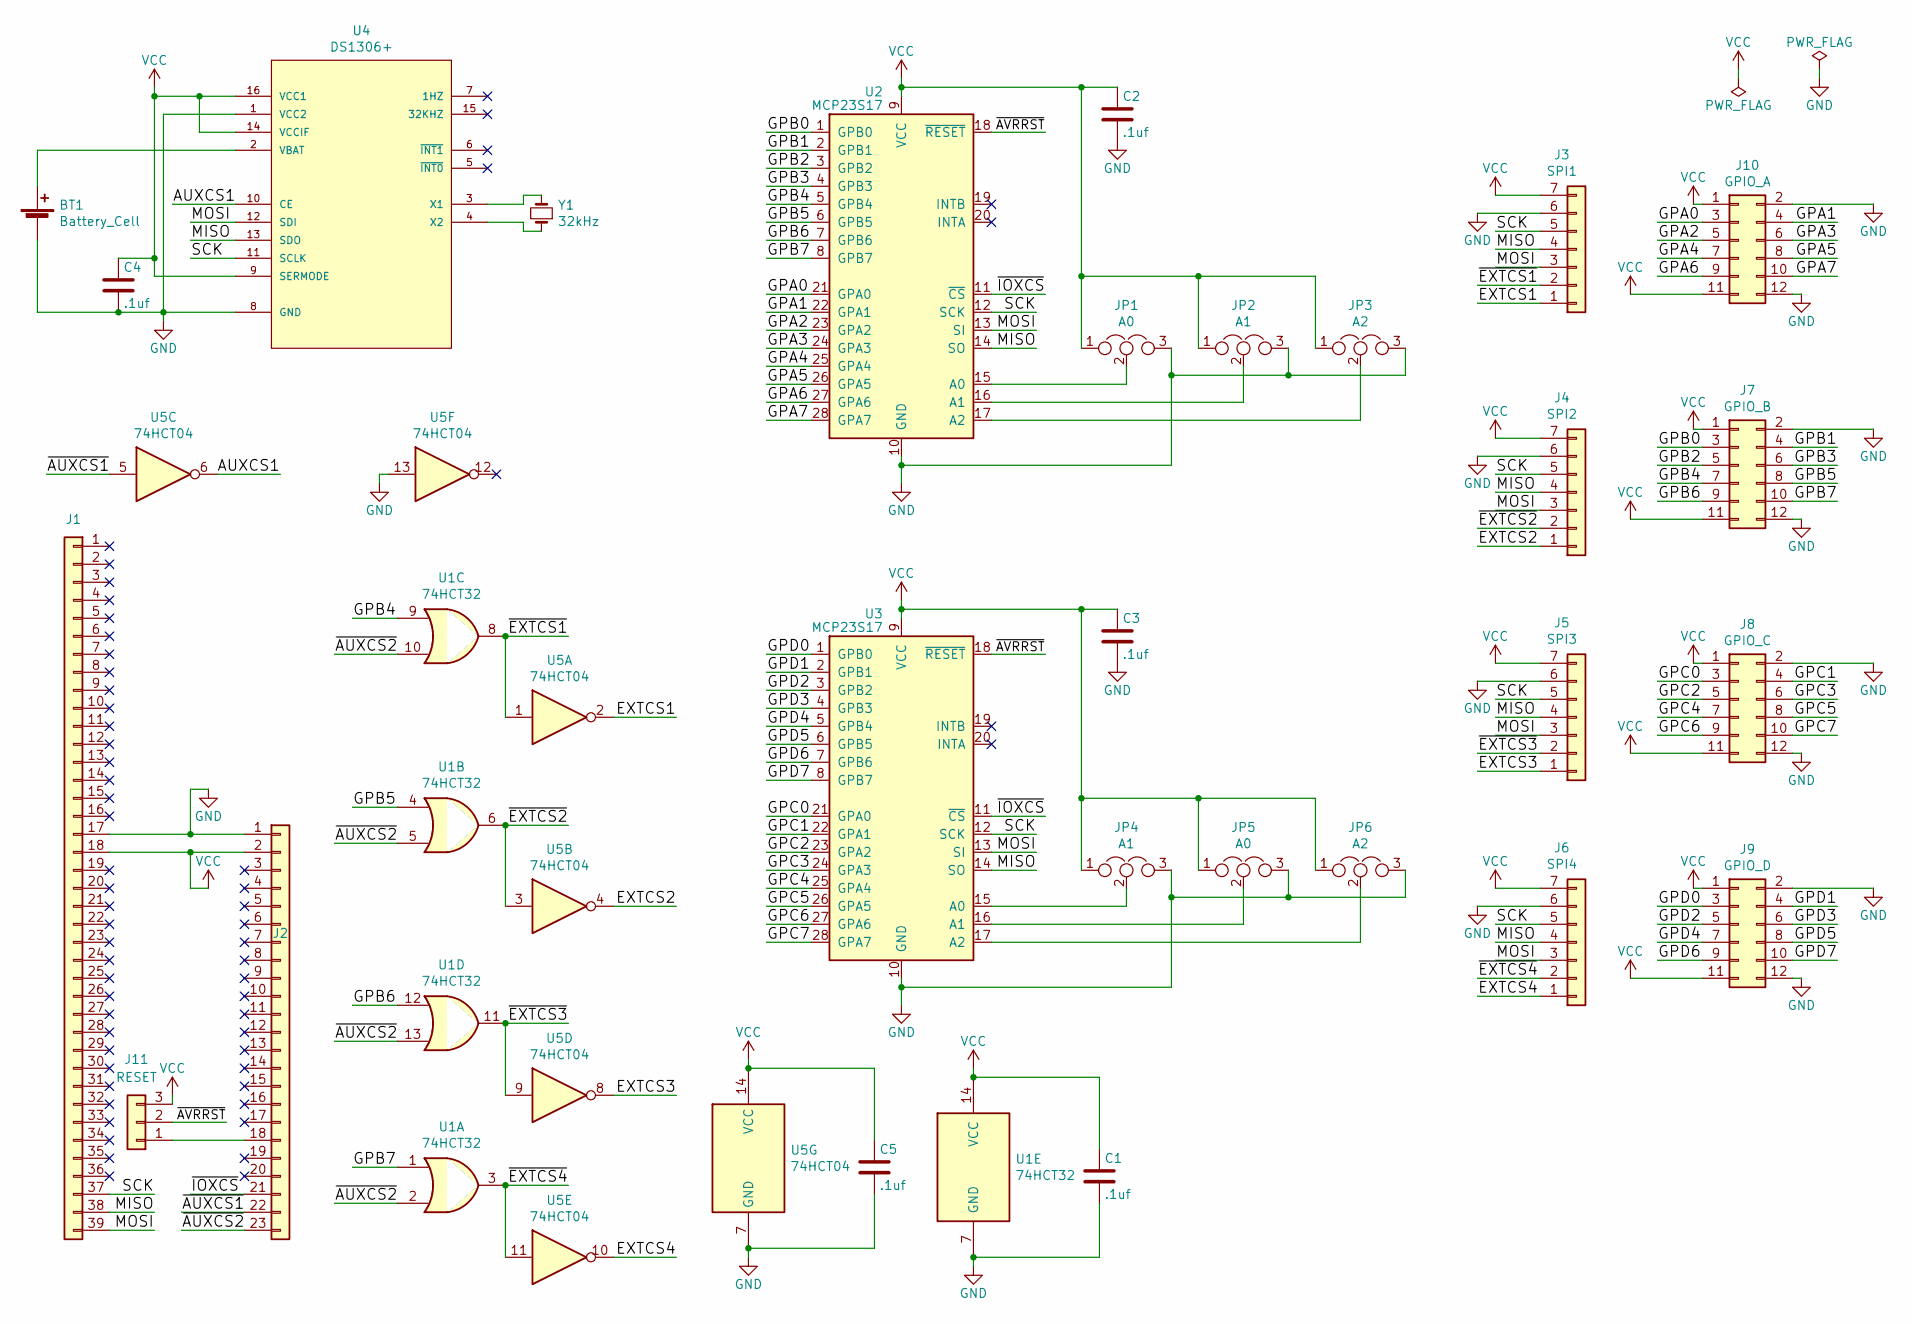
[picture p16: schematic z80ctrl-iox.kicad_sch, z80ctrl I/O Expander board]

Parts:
BT1: Battery_Cell; BatteryHolder_Keystone_3001_1x12mm
C1, C2, C3, C4, C5: .1uf; C_Disc_D3.0mm_W1.6mm_P2.50mm
J1: BUS; PinHeader_1x39_P2.54mm_Vertical; DigikeyPN s1012ec-39-nd
J2: BUSEXT; PinHeader_1x23_P2.54mm_Vertical; DigikeyPN s1012ec-39-nd
J3: SPI1; PinHeader_1x07_P2.54mm_Horizontal
J4: SPI2; PinHeader_1x07_P2.54mm_Horizontal
J5: SPI3; PinHeader_1x07_P2.54mm_Horizontal
J6: SPI4; PinHeader_1x07_P2.54mm_Horizontal
J7: GPIO_B; PinHeader_2x06_P2.54mm_Horizontal
J8: GPIO_C; PinHeader_2x06_P2.54mm_Horizontal
J9: GPIO_D; PinHeader_2x06_P2.54mm_Horizontal
J10: GPIO_A; PinHeader_2x06_P2.54mm_Horizontal
J11: RESET; PinHeader_1x03_P2.54mm_Vertical
JP1, JP5: A0; PinHeader_1x03_P2.54mm_Vertical
JP2, JP4: A1; PinHeader_1x03_P2.54mm_Vertical
JP3, JP6: A2; PinHeader_1x03_P2.54mm_Vertical
U1: 74HCT32; DIP-14_W7.62mm_Socket
U2, U3: MCP23S17; DIP-28_W7.62mm_Socket; MouserPN 579-MCP23S17-E/SP; DigikeyPN MCP23S17-E/SP-ND
U4: DS1306+; DIP-16_W7.62mm_Socket
U5: 74HCT04; DIP-14_W7.62mm_Socket
Y1: 32kHz; Crystal_DS26_D2.0mm_L6.0mm_Horizontal

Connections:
/AUXCS1: U4.10 (CE), U5.6
/EXTCS1: J3.1, U5.2
/EXTCS2: J4.1, U5.4
/EXTCS3: J5.1, U5.8
/EXTCS4: J6.1, U5.10
/GPA0: J10.3, U2.21 (GPA0)
/GPA1: J10.4, U2.22 (GPA1)
/GPA2: J10.5, U2.23 (GPA2)
/GPA3: J10.6, U2.24 (GPA3)
/GPA4: J10.7, U2.25 (GPA4)
/GPA5: J10.8, U2.26 (GPA5)
/GPA6: J10.9, U2.27 (GPA6)
/GPA7: J10.10, U2.28 (GPA7)
/GPB0: J7.3, U2.1 (GPB0)
/GPB1: J7.4, U2.2 (GPB1)
/GPB2: J7.5, U2.3 (GPB2)
/GPB3: J7.6, U2.4 (GPB3)
/GPB4: J7.7, U1.9, U2.5 (GPB4)
/GPB5: J7.8, U1.4, U2.6 (GPB5)
/GPB6: J7.9, U1.12, U2.7 (GPB6)
/GPB7: J7.10, U1.1, U2.8 (GPB7)
/GPC0: J8.3, U3.21 (GPA0)
/GPC1: J8.4, U3.22 (GPA1)
/GPC2: J8.5, U3.23 (GPA2)
/GPC3: J8.6, U3.24 (GPA3)
/GPC4: J8.7, U3.25 (GPA4)
/GPC5: J8.8, U3.26 (GPA5)
/GPC6: J8.9, U3.27 (GPA6)
/GPC7: J8.10, U3.28 (GPA7)
/GPD0: J9.3, U3.1 (GPB0)
/GPD1: J9.4, U3.2 (GPB1)
/GPD2: J9.5, U3.3 (GPB2)
/GPD3: J9.6, U3.4 (GPB3)
/GPD4: J9.7, U3.5 (GPB4)
/GPD5: J9.8, U3.6 (GPB5)
/GPD6: J9.9, U3.7 (GPB6)
/GPD7: J9.10, U3.8 (GPB7)
/MISO: J1.38, J3.4, J4.4, J5.4, J6.4, U2.14 (SO), U3.14 (SO), U4.13 (SDO)
/MOSI: J1.39, J3.3, J4.3, J5.3, J6.3, U2.13 (SI), U3.13 (SI), U4.12 (SDI)
/SCK: J1.37, J3.5, J4.5, J5.5, J6.5, U2.12 (SCK), U3.12 (SCK), U4.11 (SCLK)
/~AUXCS1: J2.22, U5.5
/~AUXCS2: J2.23, U1.2, U1.5, U1.10, U1.13
/~AVRRST: J11.2, U2.18 (~RESET), U3.18 (~RESET)
/~EXTCS1: J3.2, U1.8, U5.1
/~EXTCS2: J4.2, U1.6, U5.3
/~EXTCS3: J5.2, U1.11, U5.9
/~EXTCS4: J6.2, U1.3, U5.11
/~IOXCS: J2.21, U2.11 (~CS), U3.11 (~CS)
GND: BT1.2 (-), C1.2, C2.2, C3.2, C4.2, C5.2, J1.17, J2.1, J3.6, J4.6, J5.6, J6.6, J7.2, J7.12, J8.2, J8.12, J9.2, J9.12, J10.2, J10.12, JP1.3, JP2.3, JP3.3, JP4.3, JP5.3, JP6.3, U1.7 (GND), U2.10 (GND), U3.10 (GND), U4.1 (VCC2), U4.8 (GND), U5.7 (GND), U5.13
unnamed: BT1.1 (+), U4.2 (VBAT)
unnamed: J2.18, J11.1
unnamed: JP1.2, U2.15 (A0)
unnamed: JP2.2, U2.16 (A1)
unnamed: JP3.2, U2.17 (A2)
unnamed: JP4.2, U3.15 (A0)
unnamed: JP5.2, U3.16 (A1)
unnamed: JP6.2, U3.17 (A2)
unnamed: U4.3 (X1), Y1.2
unnamed: U4.4 (X2), Y1.1
VCC: C1.1, C2.1, C3.1, C4.1, C5.1, J1.18, J2.2, J3.7, J4.7, J5.7, J6.7, J7.1, J7.11, J8.1, J8.11, J9.1, J9.11, J10.1, J10.11, J11.3, JP1.1, JP2.1, JP3.1, JP4.1, JP5.1, JP6.1, U1.14 (VCC), U2.9 (VCC), U3.9 (VCC), U4.9 (SERMODE), U4.14 (VCCIF), U4.16 (VCC1), U5.14 (VCC)

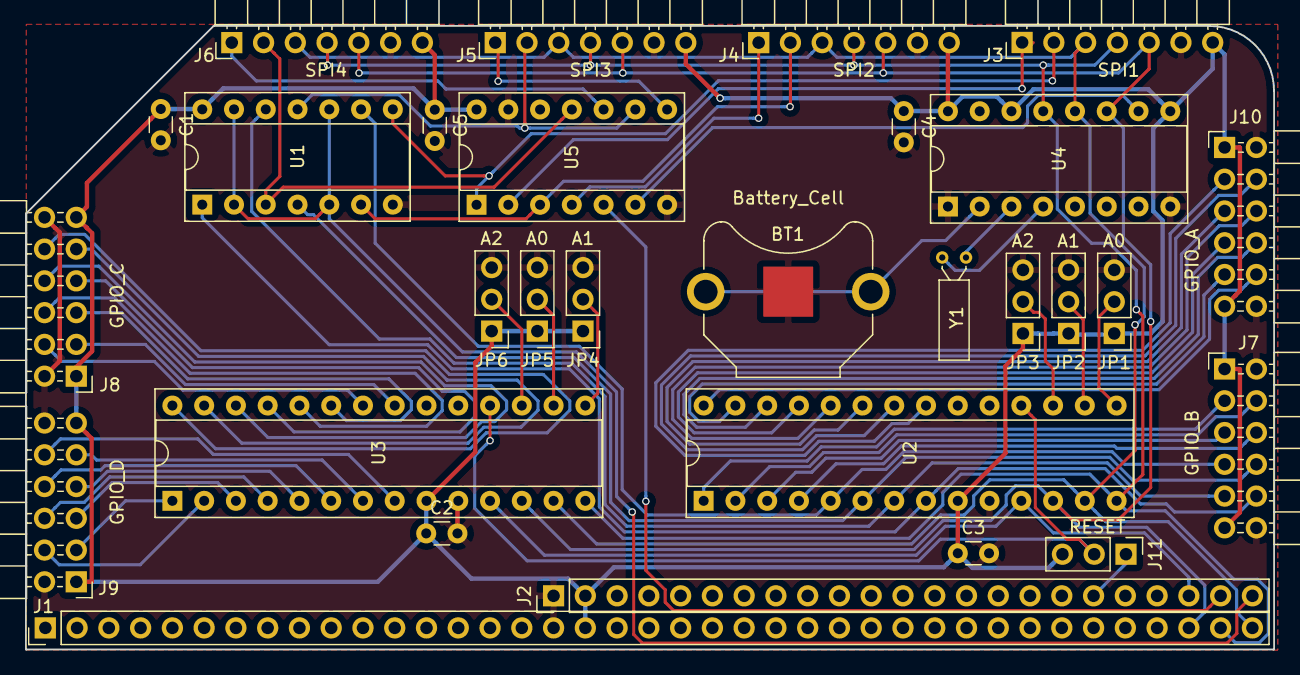
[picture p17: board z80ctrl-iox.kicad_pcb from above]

Board: 2 copper layers, 99.8 x 49.9 mm, 29 parts (0 on the bottom side), 60 nets.

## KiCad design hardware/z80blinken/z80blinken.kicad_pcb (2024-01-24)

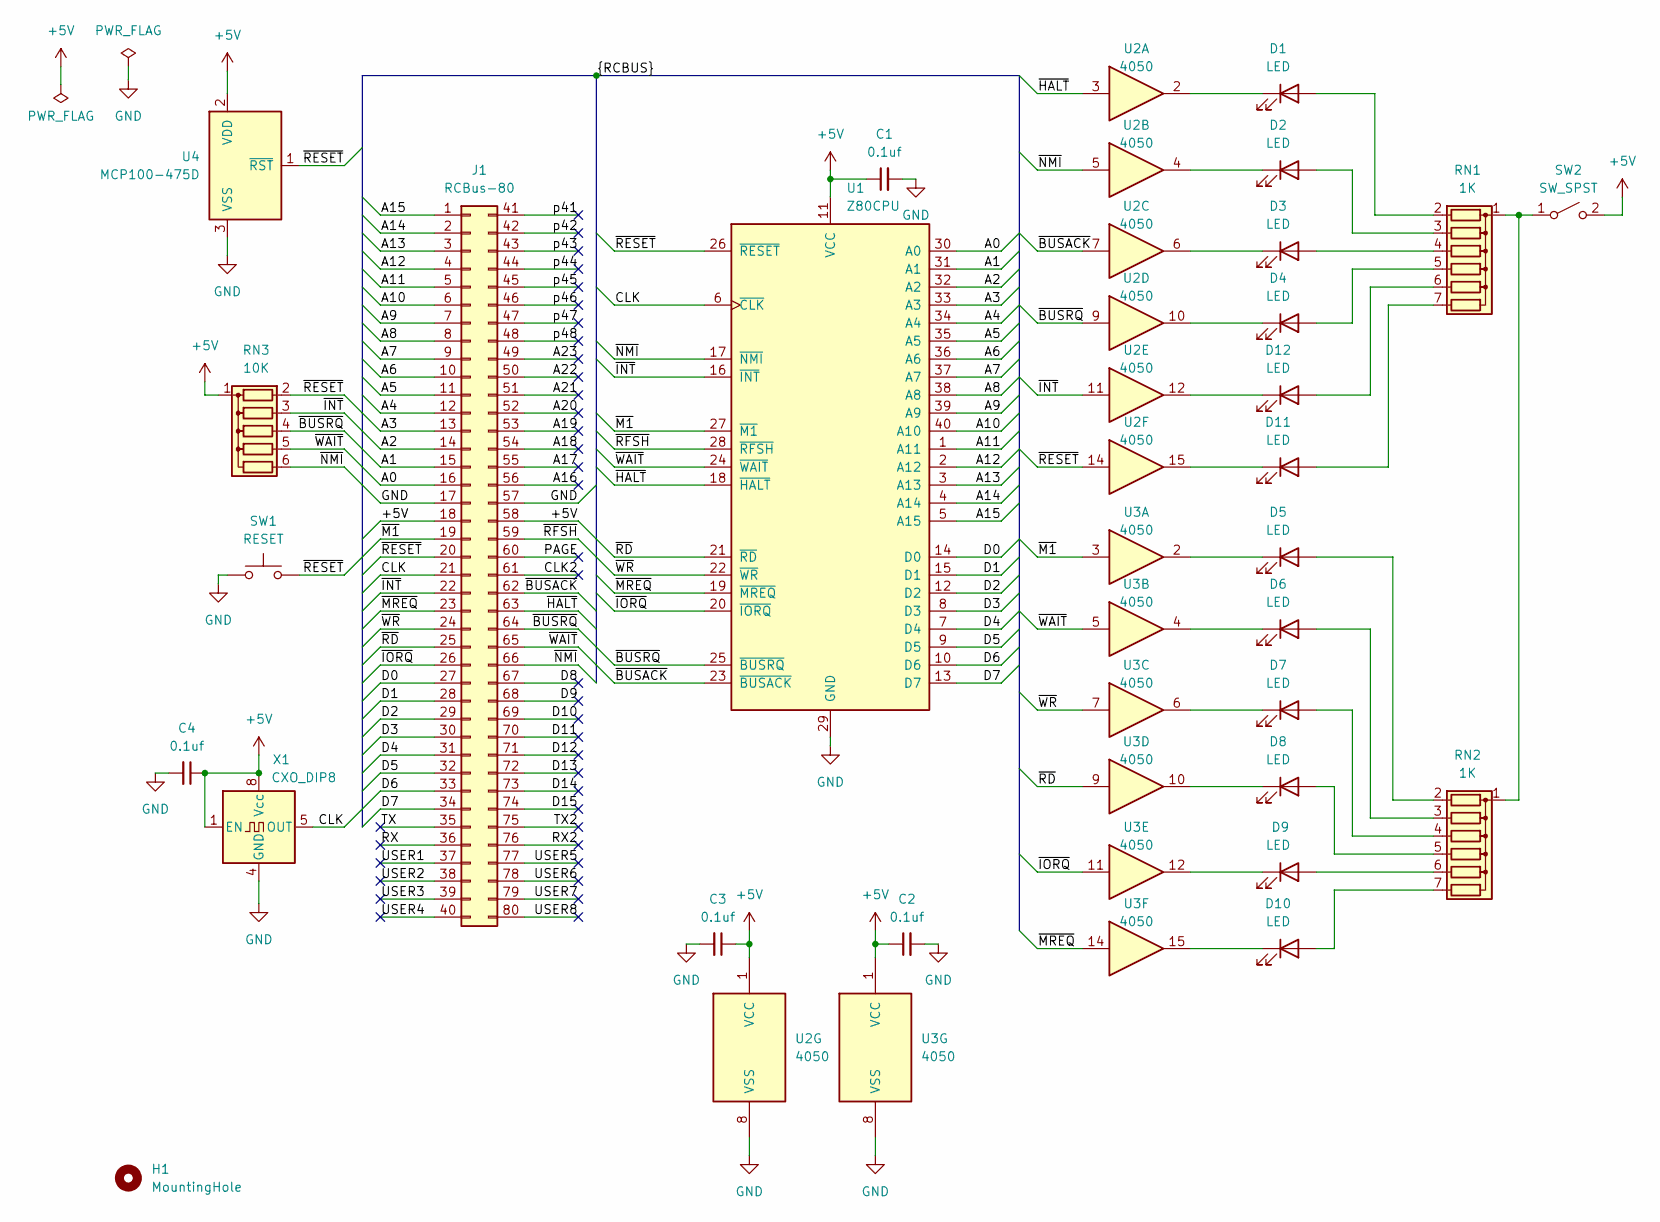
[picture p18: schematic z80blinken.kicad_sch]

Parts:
C1, C2, C3, C4: 0.1uf; C_Disc_D3.0mm_W1.6mm_P2.50mm
D1, D2, D3, D4, D5, D6, D7, D8, D9, D10, D11, D12: LED; LED_WP934CB&slash_GD_KNB
H1: MountingHole; MountingHole_3.2mm_M3
J1: RCBus-80
RN1, RN2: 1K; R_Array_SIP7
RN3: 10K; R_Array_SIP6
SW1: RESET; SW_Tactile_SPST_Angled_PTS645Vx31-2LFS
SW2: SW_SPST; JS202011CQN
U1: Z80CPU; DIP-40_W15.24mm
U2, U3: 4050; DIP-16_W7.62mm
U4: MCP100-475D; TO-92_Inline
X1: CXO_DIP8; Oscillator_DIP-8

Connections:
+5V: C1.1, C2.1, C3.1, C4.1, J1.18, J1.58, RN3.1 (common), SW2.2 (B), U1.11 (VCC), U2.1 (VCC), U3.1 (VCC), U4.2 (VDD), X1.1 (EN), X1.8 (Vcc)
/A0: J1.16, U1.30 (A0)
/A1: J1.15, U1.31 (A1)
/A2: J1.14, U1.32 (A2)
/A3: J1.13, U1.33 (A3)
/A4: J1.12, U1.34 (A4)
/A5: J1.11, U1.35 (A5)
/A6: J1.10, U1.36 (A6)
/A7: J1.9, U1.37 (A7)
/A8: J1.8, U1.38 (A8)
/A9: J1.7, U1.39 (A9)
/A10: J1.6, U1.40 (A10)
/A11: J1.5, U1.1 (A11)
/A12: J1.4, U1.2 (A12)
/A13: J1.3, U1.3 (A13)
/A14: J1.2, U1.4 (A14)
/A15: J1.1, U1.5 (A15)
/A16: J1.56
/A17: J1.55
/A18: J1.54
/A19: J1.53
/A20: J1.52
/A21: J1.51
/A22: J1.50
/A23: J1.49
/CLK: J1.21, U1.6 (~CLK), X1.5 (OUT)
/CLK2: J1.61
/D0: J1.27, U1.14 (D0)
/D1: J1.28, U1.15 (D1)
/D2: J1.29, U1.12 (D2)
/D3: J1.30, U1.8 (D3)
/D4: J1.31, U1.7 (D4)
/D5: J1.32, U1.9 (D5)
/D6: J1.33, U1.10 (D6)
/D7: J1.34, U1.13 (D7)
/D8: J1.67
/D9: J1.68
/D10: J1.69
/D11: J1.70
/D12: J1.71
/D13: J1.72
/D14: J1.73
/D15: J1.74
/PAGE: J1.60
/RX: J1.36
/RX2: J1.76
/TX: J1.35
/TX2: J1.75
/USER1: J1.37
/USER2: J1.38
/USER3: J1.39
/USER4: J1.40
/USER5: J1.77
/USER6: J1.78
/USER7: J1.79
/USER8: J1.80
/p41: J1.41
/p42: J1.42
/p43: J1.43
/p44: J1.44
/p45: J1.45
/p46: J1.46
/p47: J1.47
/p48: J1.48
/~BUSACK: J1.62, U1.23 (~BUSACK), U2.7
/~BUSRQ: J1.64, RN3.4 (R3), U1.25 (~BUSRQ), U2.9
/~HALT: J1.63, U1.18 (~HALT), U2.3
/~INT: J1.22, RN3.3 (R2), U1.16 (~INT), U2.11
/~IORQ: J1.26, U1.20 (~IORQ), U3.11
/~M1: J1.19, U1.27 (~M1), U3.3
/~MREQ: J1.23, U1.19 (~MREQ), U3.14
/~NMI: J1.66, RN3.6 (R5), U1.17 (~NMI), U2.5
/~RD: J1.25, U1.21 (~RD), U3.9
/~RESET: J1.20, RN3.2 (R1), SW1.2, U1.26 (~RESET), U2.14, U4.1 (~RST)
/~RFSH: J1.59, U1.28 (~RFSH)
/~WAIT: J1.65, RN3.5 (R4), U1.24 (~WAIT), U3.5
/~WR: J1.24, U1.22 (~WR), U3.7
GND: C1.2, C2.2, C3.2, C4.2, J1.17, J1.57, SW1.1, U1.29 (GND), U2.8 (VSS), U3.8 (VSS), U4.3 (VSS), X1.4 (GND)
unnamed: D1.2 (A), RN1.2 (R1)
unnamed: D1.1 (K), U2.2
unnamed: D2.2 (A), RN1.3 (R2)
unnamed: D2.1 (K), U2.4
unnamed: D3.2 (A), RN1.4 (R3)
unnamed: D3.1 (K), U2.6
unnamed: D4.2 (A), RN1.5 (R4)
unnamed: D4.1 (K), U2.10
unnamed: D5.2 (A), RN2.2 (R1)
unnamed: D5.1 (K), U3.2
unnamed: D6.2 (A), RN2.3 (R2)
unnamed: D6.1 (K), U3.4
unnamed: D7.2 (A), RN2.4 (R3)
unnamed: D7.1 (K), U3.6
unnamed: D8.2 (A), RN2.5 (R4)
unnamed: D8.1 (K), U3.10
unnamed: D9.2 (A), RN2.6 (R5)
unnamed: D9.1 (K), U3.12
unnamed: D10.2 (A), RN2.7 (R6)
unnamed: D10.1 (K), U3.15
unnamed: D11.2 (A), RN1.7 (R6)
unnamed: D11.1 (K), U2.15
unnamed: D12.2 (A), RN1.6 (R5)
unnamed: D12.1 (K), U2.12
unnamed: RN1.1 (common), RN2.1 (common), SW2.1 (A)

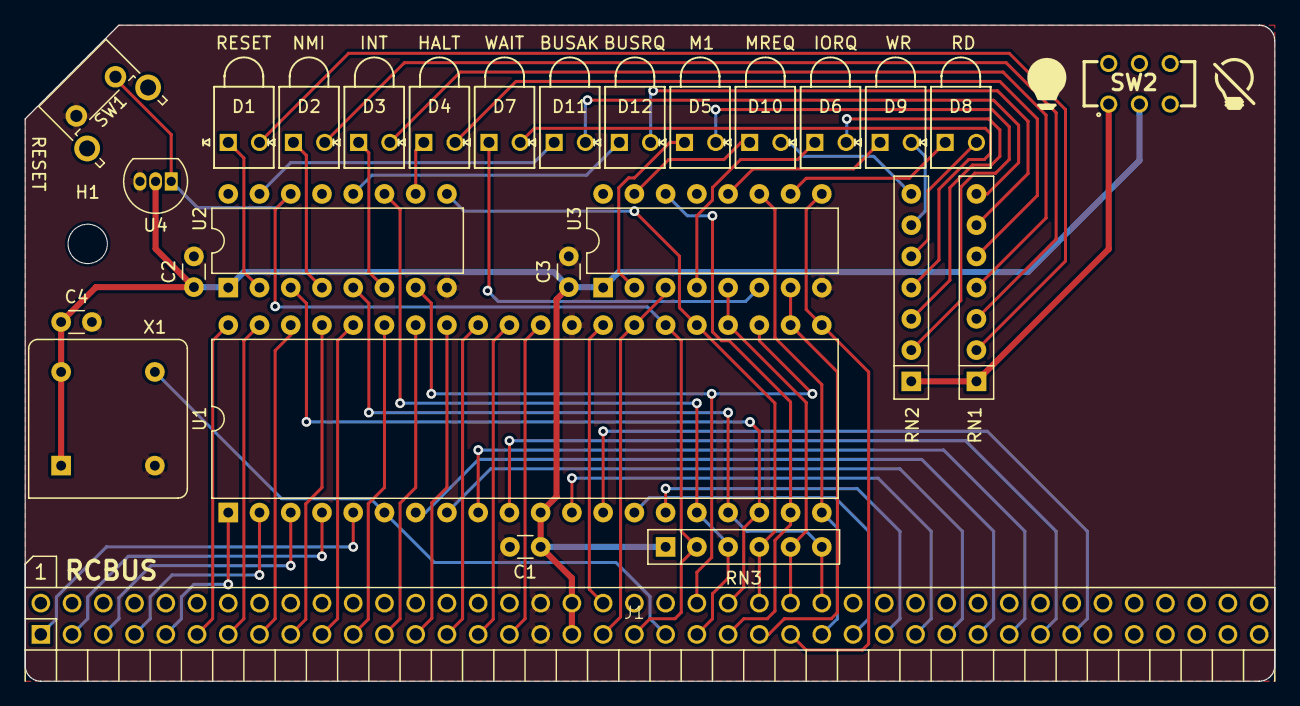
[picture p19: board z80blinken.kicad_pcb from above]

Board: 2 copper layers, 101.6 x 53.3 mm, 28 parts (0 on the bottom side), 65 nets.

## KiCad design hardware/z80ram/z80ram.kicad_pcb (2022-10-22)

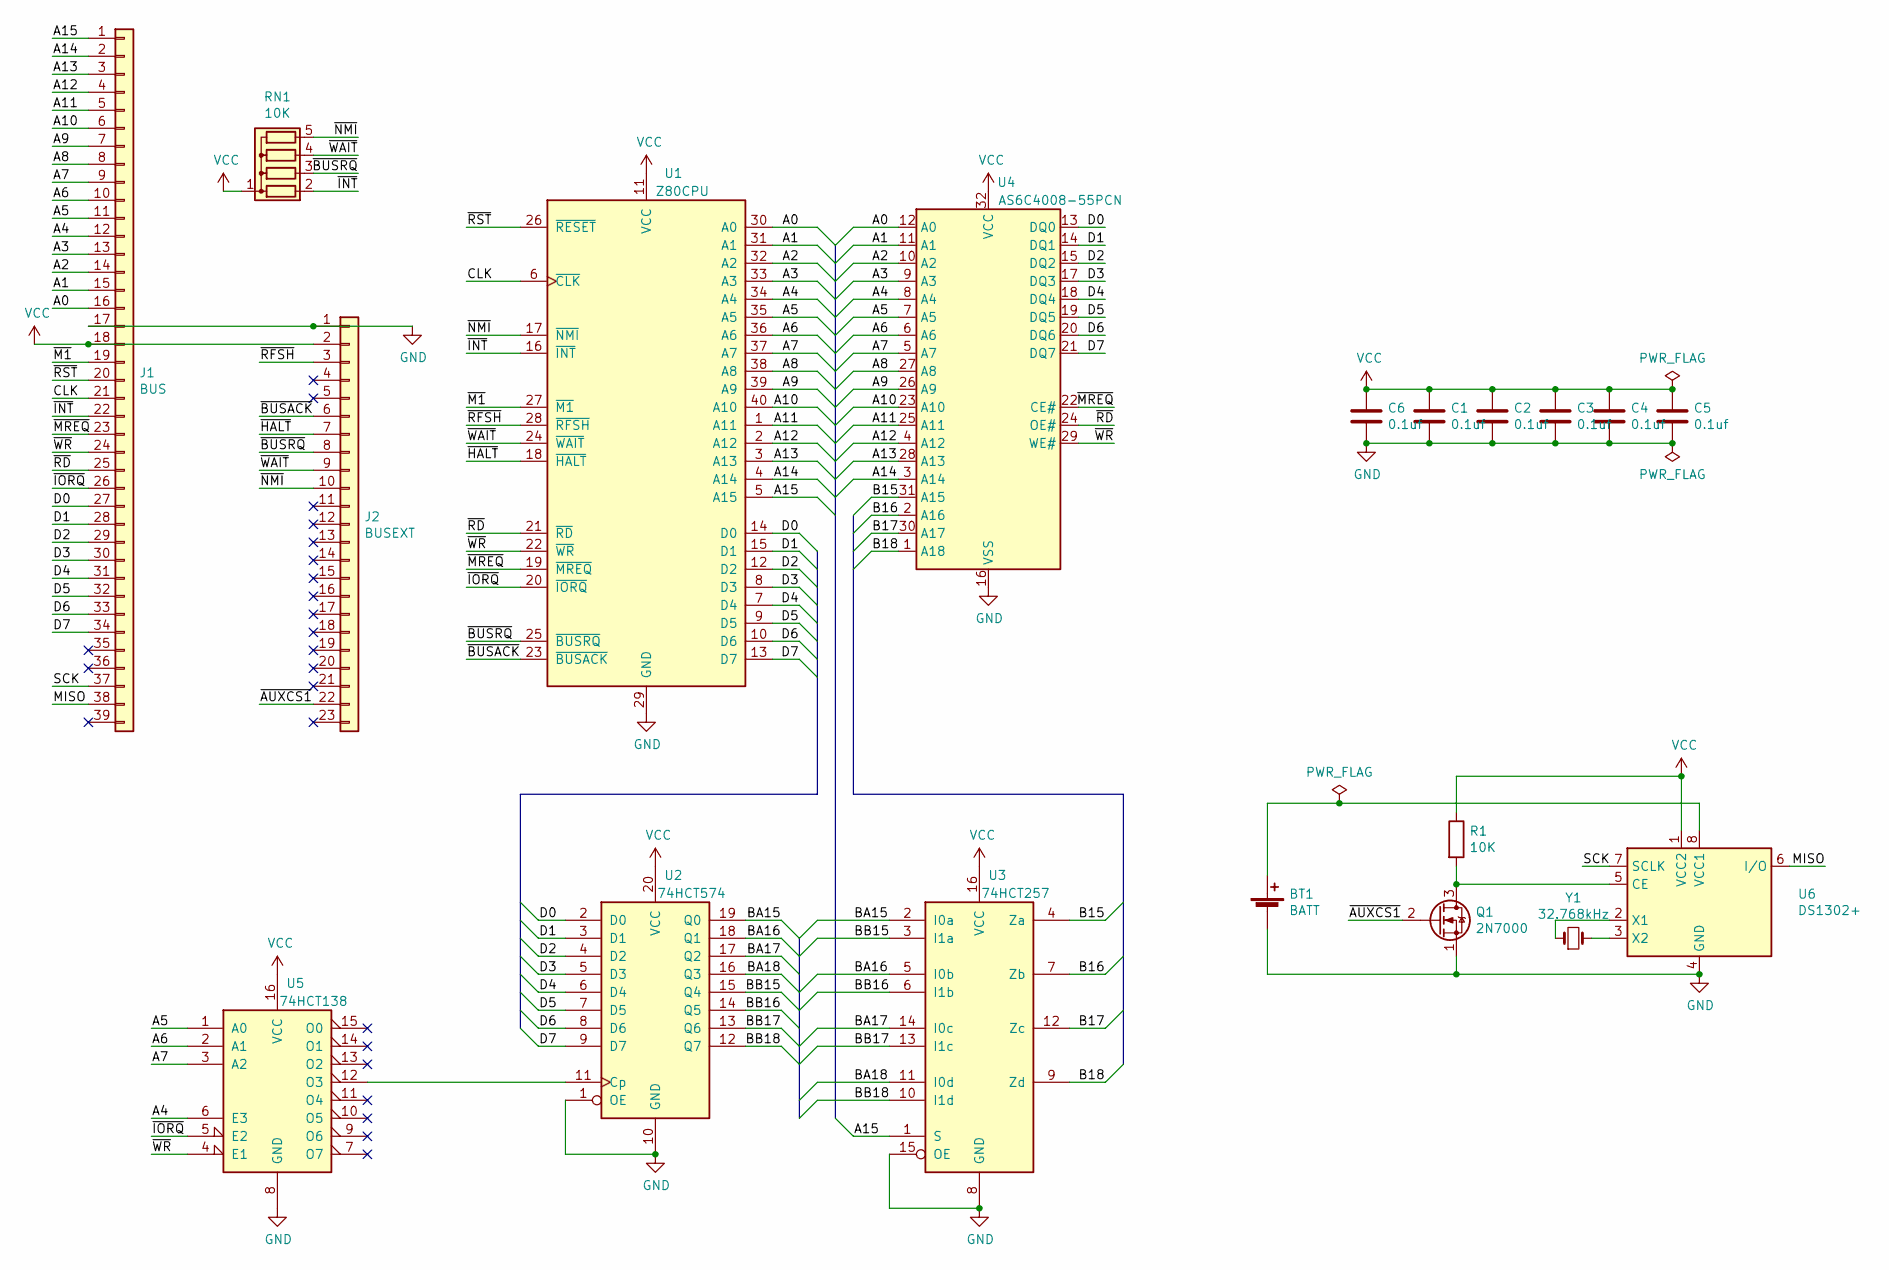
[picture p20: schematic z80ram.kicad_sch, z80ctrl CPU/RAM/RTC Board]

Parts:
BT1: BATT; BatteryHolder_Keystone_3001_1x12mm; MouserPN 534-3001; DigikeyPN 36-3001-ND
C1, C3, C4, C5, C6: 0.1uf; C_Disc_D3.0mm_W1.6mm_P2.50mm; MouserPN 594-K104M15X7RF53L2; DigikeyPN BC5142-ND
C2: 0.1uf; C_Disc_D3.0mm_W1.6mm_P2.50mm; DigikeyPN BC5142-ND
J1: BUS; PinHeader_1x39_P2.54mm_Vertical; MouserPN 517-5121TG; DigikeyPN 2057-PH2RA-80-UA-ND
J2: BUSEXT; PinHeader_1x23_P2.54mm_Vertical; MouserPN 517-5121TG; DigikeyPN 2057-PH2RA-80-UA-ND
Q1: 2N7000; TO-92_Inline; MouserPN 512-2N7000; DigikeyPN 2N7000FS-ND
R1: 10K; R_Axial_DIN0207_L6.3mm_D2.5mm_P7.62mm_Horizontal; MouserPN 603-CFR-25JB-52-10K; DigikeyPN 10KQBK-ND
RN1: 10K; R_Array_SIP5; MouserPN 652-4605M-1LF-10K; DigikeyPN 4605M-101-103LF-ND
U1: Z80CPU; DIP-40_W15.24mm; MouserPN 692-Z84C0010PEG; DigikeyPN 269-3898-ND
U2: 74HCT574; DIP-20_W7.62mm; MouserPN 595-SN74HCT574N; DigikeyPN 296-1623-5-ND
U3: 74HCT257; DIP-16_W7.62mm; MouserPN 595-SN74HCT257N; DigikeyPN 296-8406-5-ND
U4: AS6C4008-55PCN; DIP-32_W15.24mm; MouserPN 913-AS6C4008-55PCN; DigikeyPN 1450-1027-ND
U5: 74HCT138; DIP-16_W7.62mm; MouserPN 595-SN74HCT138N; DigikeyPN 296-1608-5-ND
U6: DS1302+; DIP-8_W7.62mm; MouserPN 700-DS1302; DigikeyPN DS1302+-ND
Y1: 32.768kHz; Crystal_DS26_D2.0mm_L6.0mm_Horizontal; MouserPN 695-CFS-20632768DZBB; DigikeyPN 300-8301-ND

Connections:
/A0: J1.16, U1.30 (A0), U4.12 (A0)
/A1: J1.15, U1.31 (A1), U4.11 (A1)
/A2: J1.14, U1.32 (A2), U4.10 (A2)
/A3: J1.13, U1.33 (A3), U4.9 (A3)
/A4: J1.12, U1.34 (A4), U4.8 (A4), U5.6 (E3)
/A5: J1.11, U1.35 (A5), U4.7 (A5), U5.1 (A0)
/A6: J1.10, U1.36 (A6), U4.6 (A6), U5.2 (A1)
/A7: J1.9, U1.37 (A7), U4.5 (A7), U5.3 (A2)
/A8: J1.8, U1.38 (A8), U4.27 (A8)
/A9: J1.7, U1.39 (A9), U4.26 (A9)
/A10: J1.6, U1.40 (A10), U4.23 (A10)
/A11: J1.5, U1.1 (A11), U4.25 (A11)
/A12: J1.4, U1.2 (A12), U4.4 (A12)
/A13: J1.3, U1.3 (A13), U4.28 (A13)
/A14: J1.2, U1.4 (A14), U4.3 (A14)
/A15: J1.1, U1.5 (A15), U3.1 (S)
/B15: U3.4 (Za), U4.31 (A15)
/B16: U3.7 (Zb), U4.2 (A16)
/B17: U3.12 (Zc), U4.30 (A17)
/B18: U3.9 (Zd), U4.1 (A18)
/BA15: U2.19 (Q0), U3.2 (I0a)
/BA16: U2.18 (Q1), U3.5 (I0b)
/BA17: U2.17 (Q2), U3.14 (I0c)
/BA18: U2.16 (Q3), U3.11 (I0d)
/BB15: U2.15 (Q4), U3.3 (I1a)
/BB16: U2.14 (Q5), U3.6 (I1b)
/BB17: U2.13 (Q6), U3.13 (I1c)
/BB18: U2.12 (Q7), U3.10 (I1d)
/CLK: J1.21, U1.6 (~CLK)
/D0: J1.27, U1.14 (D0), U2.2 (D0), U4.13 (DQ0)
/D1: J1.28, U1.15 (D1), U2.3 (D1), U4.14 (DQ1)
/D2: J1.29, U1.12 (D2), U2.4 (D2), U4.15 (DQ2)
/D3: J1.30, U1.8 (D3), U2.5 (D3), U4.17 (DQ3)
/D4: J1.31, U1.7 (D4), U2.6 (D4), U4.18 (DQ4)
/D5: J1.32, U1.9 (D5), U2.7 (D5), U4.19 (DQ5)
/D6: J1.33, U1.10 (D6), U2.8 (D6), U4.20 (DQ6)
/D7: J1.34, U1.13 (D7), U2.9 (D7), U4.21 (DQ7)
/MISO: J1.38, U6.6 (I/O)
/SCK: J1.37, U6.7 (SCLK)
/~AUXCS1: J2.22, Q1.2 (G)
/~BUSACK: J2.6, U1.23 (~BUSACK)
/~BUSRQ: J2.8, RN1.3 (R2), U1.25 (~BUSRQ)
/~HALT: J2.7, U1.18 (~HALT)
/~INT: J1.22, RN1.2 (R1), U1.16 (~INT)
/~IORQ: J1.26, U1.20 (~IORQ), U5.5 (E2)
/~M1: J1.19, U1.27 (~M1)
/~MREQ: J1.23, U1.19 (~MREQ), U4.22 (CE#)
/~NMI: J2.10, RN1.5 (R4), U1.17 (~NMI)
/~RD: J1.25, U1.21 (~RD), U4.24 (OE#)
/~RFSH: J2.3, U1.28 (~RFSH)
/~RST: J1.20, U1.26 (~RESET)
/~WAIT: J2.9, RN1.4 (R3), U1.24 (~WAIT)
/~WR: J1.24, U1.22 (~WR), U4.29 (WE#), U5.4 (E1)
GND: BT1.2 (-), C1.2, C2.2, C3.2, C4.2, C5.2, C6.2, J1.17, J2.1, Q1.1 (S), U1.29 (GND), U2.1 (OE), U2.10 (GND), U3.8 (GND), U3.15 (OE), U4.16 (VSS), U5.8 (GND), U6.4 (GND)
unnamed: BT1.1 (+), U6.8 (VCC1)
unnamed: Q1.3 (D), R1.2, U6.5 (CE)
unnamed: U2.11 (Cp), U5.12 (O3)
unnamed: U6.2 (X1), Y1.1
unnamed: U6.3 (X2), Y1.2
VCC: C1.1, C2.1, C3.1, C4.1, C5.1, C6.1, J1.18, J2.2, R1.1, RN1.1 (common), U1.11 (VCC), U2.20 (VCC), U3.16 (VCC), U4.32 (VCC), U5.16 (VCC), U6.1 (VCC2)

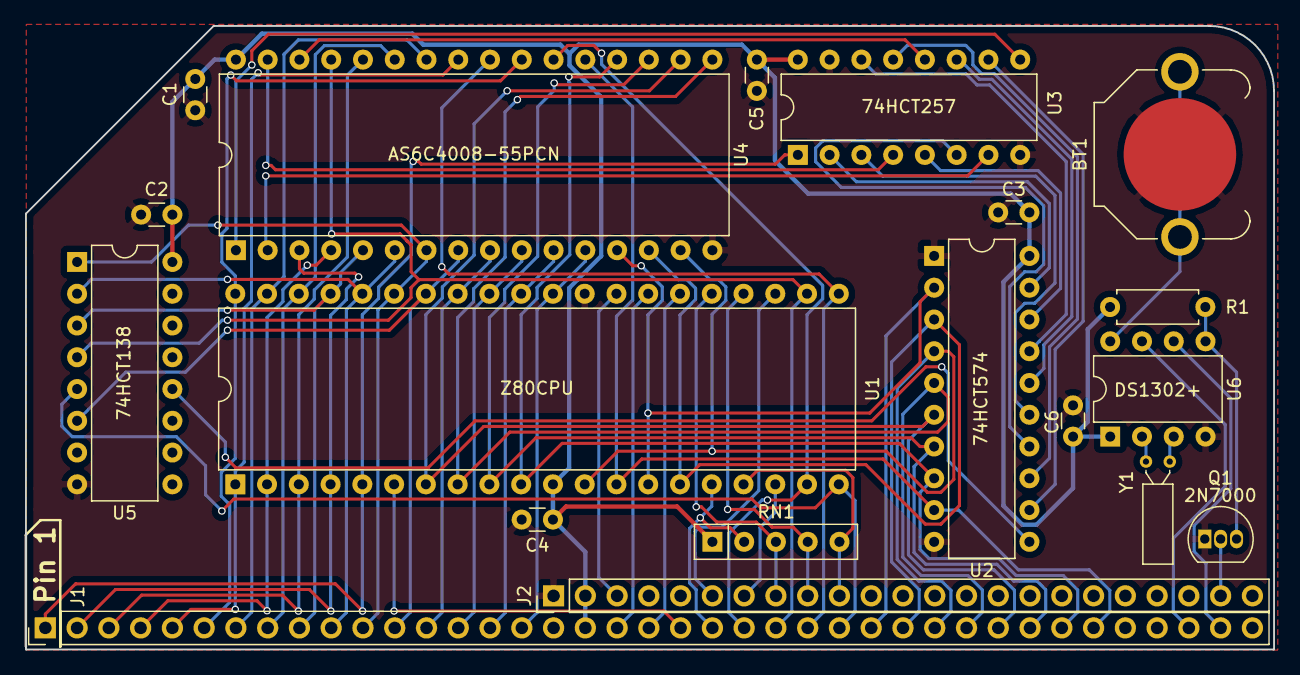
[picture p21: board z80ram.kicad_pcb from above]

Board: 2 copper layers, 99.8 x 49.9 mm, 19 parts (0 on the bottom side), 60 nets.

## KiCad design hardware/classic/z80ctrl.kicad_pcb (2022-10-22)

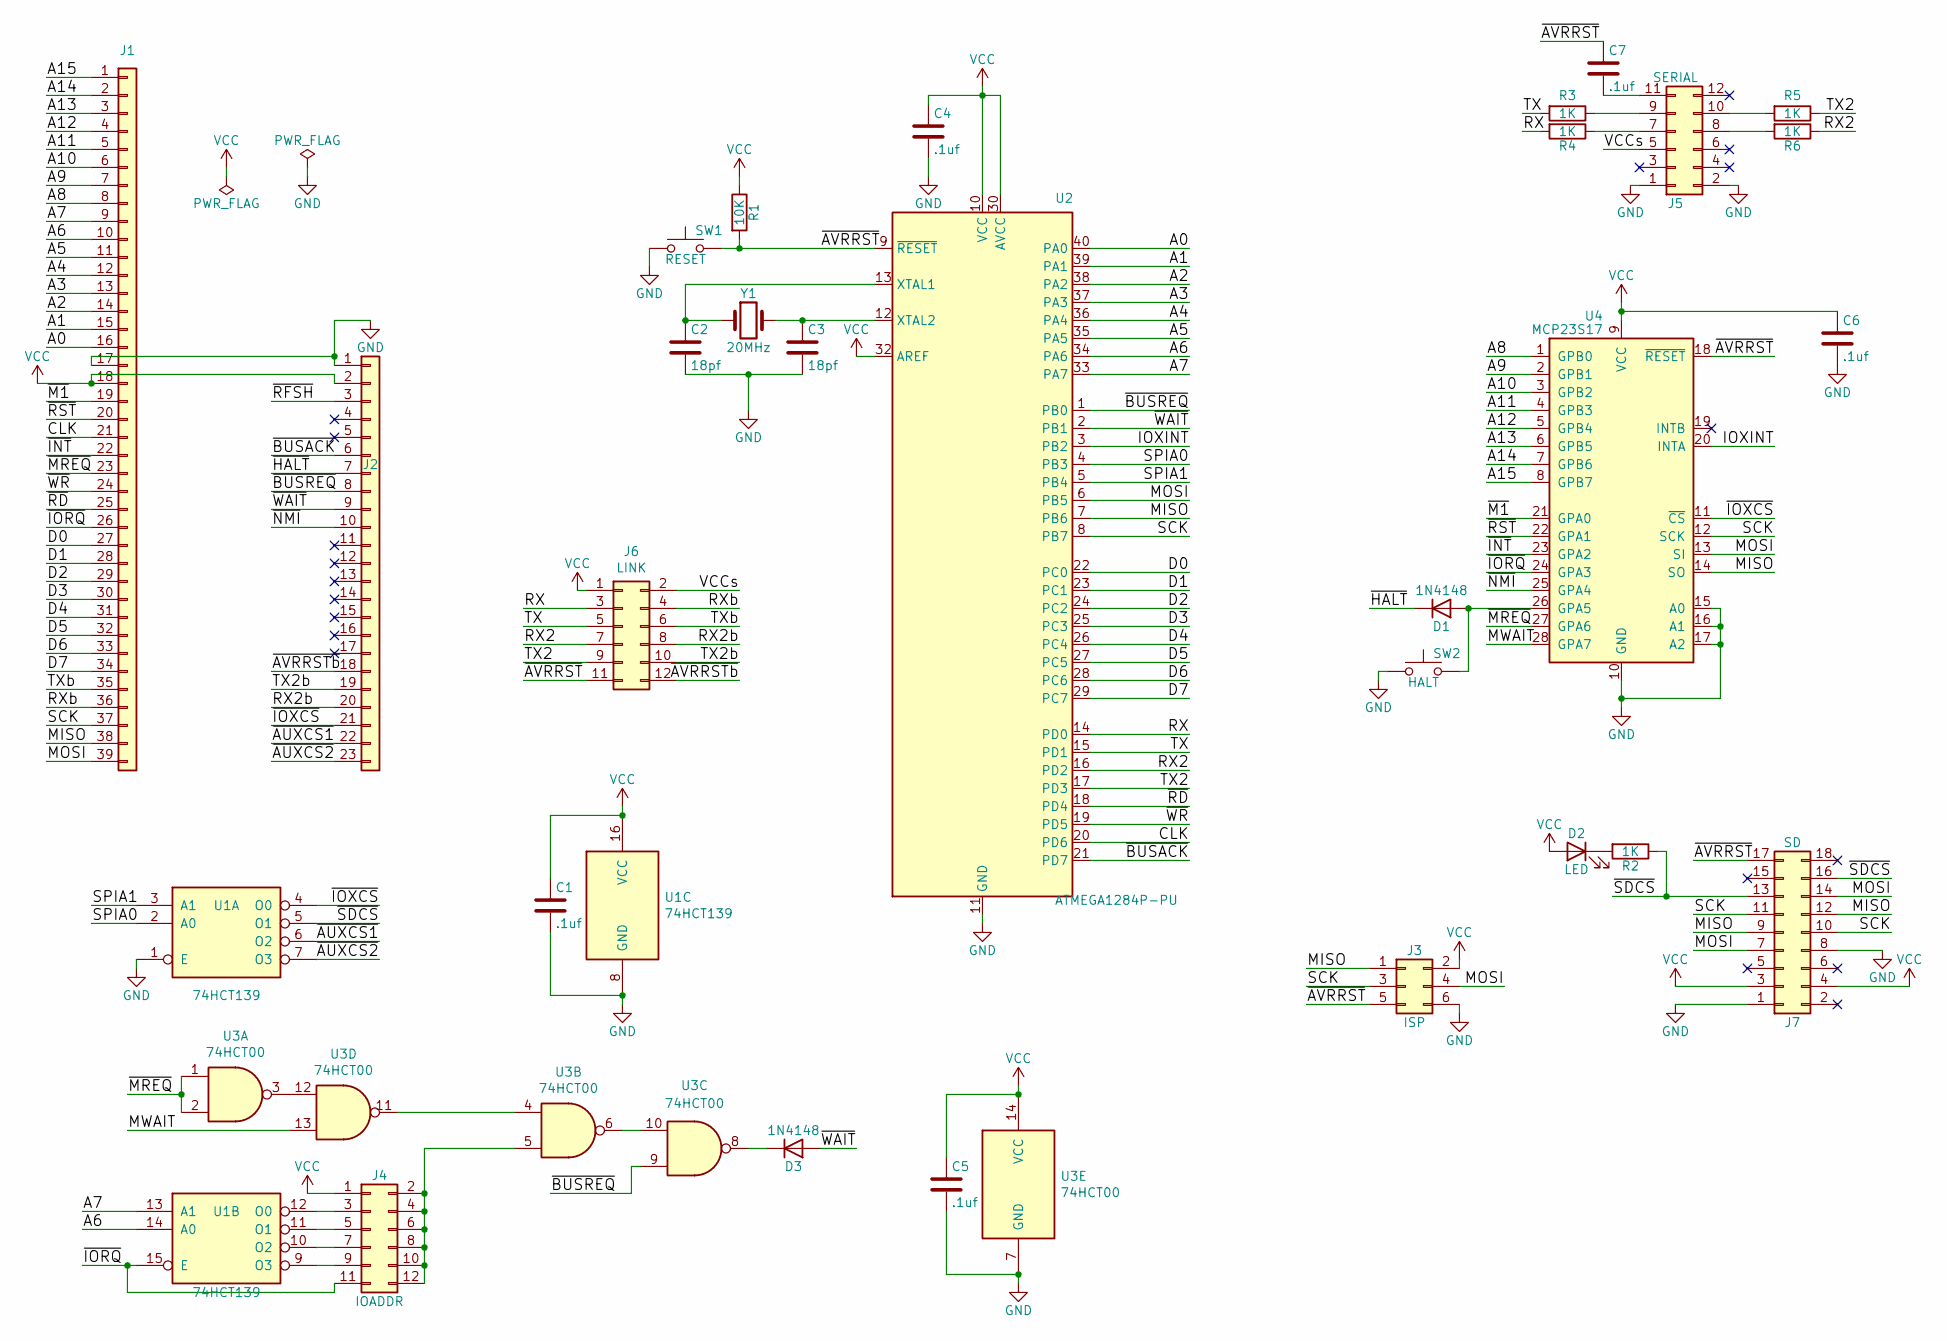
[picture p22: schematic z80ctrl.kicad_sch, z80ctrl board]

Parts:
C1, C4, C5, C6, C7: .1uf; C_Disc_D3.0mm_W1.6mm_P2.50mm; MouserPN 594-K104M15X7RF53L2; DigikeyPN BC5142-ND
C2: 18pf; C_Disc_D3.0mm_W1.6mm_P2.50mm; MouserPN 594-K180J15C0GF5TL2
C3: 18pf; C_Disc_D3.0mm_W1.6mm_P2.50mm; MouserPN 594-K180J15C0GF5TL2; DigikeyPN BC1004CT-ND
D1, D3: 1N4148; D_DO-35_SOD27_P7.62mm_Horizontal; MouserPN 512-1N4148; DigikeyPN 1N4148FS-ND
D2: LED; LED_D3.0mm; MouserPN 859-LTL2R3KGD-EM
J1: BUS; PinHeader_1x39_P2.54mm_Vertical; MouserPN 517-5121TG; DigikeyPN 2057-PH2RA-80-UA-ND
J2: BUSEXT; PinHeader_1x23_P2.54mm_Vertical; MouserPN 517-5121TG; DigikeyPN 2057-PH2RA-80-UA-ND
J3: ISP; PinHeader_2x03_P2.54mm_Vertical; MouserPN 710-61304011121; DigikeyPN S1012EC-40-ND
J4: IOADDR; PinHeader_2x06_P2.54mm_Vertical; MouserPN 710-61304011121; DigikeyPN S1012EC-40-ND
J5: SERIAL; PinHeader_2x06_P2.54mm_Horizontal; MouserPN 649-1012938291204BLF; DigikeyPN PH2RA-12-UA
J6: LINK; PinHeader_2x06_P2.54mm_Vertical; MouserPN 710-61304011121; DigikeyPN S1012EC-40-ND
J7: SD; PinHeader_2x09_P2.54mm_Vertical; MouserPN 485-254
R1: 10K; R_Axial_DIN0207_L6.3mm_D2.5mm_P7.62mm_Horizontal; MouserPN 603-CFR-25JB-52-10K; DigikeyPN 10KQBK-ND
R2, R3, R4, R5, R6: 1K; R_Axial_DIN0207_L6.3mm_D2.5mm_P7.62mm_Horizontal; MouserPN 603-CFR-25JB-1K0
SW1: RESET; SW_PUSH_6mm_H4.3mm; MouserPN 506-FSM4JH; DigikeyPN 450-1650-ND
SW2: HALT; SW_PUSH_6mm_H4.3mm; MouserPN 506-FSM4JH
U1: 74HCT139; DIP-16_W7.62mm_Socket; MouserPN 595-SN74HCT139N; DigikeyPN 296-8390-5-ND
U2: ATMEGA1284P-PU; DIP-40_W15.24mm_Socket; MouserPN 556-ATMEGA1284P-PU; DigikeyPN ATMEGA1284P-PU-ND
U3: 74HCT00; DIP-14_W7.62mm_Socket; MouserPN 595-SN74HCT00N; DigikeyPN 296-1603-5-ND
U4: MCP23S17; DIP-28_W7.62mm_Socket; MouserPN 579-MCP23S17-E/SP; DigikeyPN MCP23S17-E/SP-ND
Y1: 20MHz; Crystal_HC49-4H_Vertical; MouserPN 815-ABL-20-B2; DigikeyPN 535-9046-ND

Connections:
/A0: J1.16, U2.40 (PA0)
/A1: J1.15, U2.39 (PA1)
/A2: J1.14, U2.38 (PA2)
/A3: J1.13, U2.37 (PA3)
/A4: J1.12, U2.36 (PA4)
/A5: J1.11, U2.35 (PA5)
/A6: J1.10, U1.14 (A0), U2.34 (PA6)
/A7: J1.9, U1.13 (A1), U2.33 (PA7)
/A8: J1.8, U4.1 (GPB0)
/A9: J1.7, U4.2 (GPB1)
/A10: J1.6, U4.3 (GPB2)
/A11: J1.5, U4.4 (GPB3)
/A12: J1.4, U4.5 (GPB4)
/A13: J1.3, U4.6 (GPB5)
/A14: J1.2, U4.7 (GPB6)
/A15: J1.1, U4.8 (GPB7)
/CLK: J1.21, U2.20 (PD6)
/D0: J1.27, U2.22 (PC0)
/D1: J1.28, U2.23 (PC1)
/D2: J1.29, U2.24 (PC2)
/D3: J1.30, U2.25 (PC3)
/D4: J1.31, U2.26 (PC4)
/D5: J1.32, U2.27 (PC5)
/D6: J1.33, U2.28 (PC6)
/D7: J1.34, U2.29 (PC7)
/IOXINT: U2.3 (PB2), U4.20 (INTA)
/MISO: J1.38, J3.1, J7.9, J7.12, U2.7 (PB6), U4.14 (SO)
/MOSI: J1.39, J3.4, J7.7, J7.14, U2.6 (PB5), U4.13 (SI)
/MWAIT: U3.13, U4.28 (GPA7)
/RX: J6.3, R4.2, U2.14 (PD0)
/RX2: J6.7, R6.1, U2.16 (PD2)
/RX2b: J2.20, J6.8
/RXb: J1.36, J6.4
/SCK: J1.37, J3.3, J7.10, J7.11, U2.8 (PB7), U4.12 (SCK)
/SPIA0: U1.2 (A0), U2.4 (PB3)
/SPIA1: U1.3 (A1), U2.5 (PB4)
/TX: J6.5, R3.2, U2.15 (PD1)
/TX2: J6.9, R5.1, U2.17 (PD3)
/TX2b: J2.19, J6.10
/TXb: J1.35, J6.6
/VCCs: J5.5, J6.2
/~AUXCS1: J2.22, U1.6 (O2)
/~AUXCS2: J2.23, U1.7 (O3)
/~AVRRSTb: J2.18, J6.12
/~AVRRST: C7.1, J3.5, J6.11, J7.17, R1.2, SW1.2, U2.9 (~RESET), U4.18 (~RESET)
/~BUSACK: J2.6, U2.21 (PD7)
/~BUSREQ: J2.8, U2.1 (PB0), U3.9
/~HALT: D1.1 (K), J2.7
/~INT: J1.22, U4.23 (GPA2)
/~IORQ: J1.26, J4.11, U1.15 (E), U4.24 (GPA3)
/~IOXCS: J2.21, U1.4 (O0), U4.11 (~CS)
/~M1: J1.19, U4.21 (GPA0)
/~MREQ: J1.23, U3.1, U3.2, U4.27 (GPA6)
/~NMI: J2.10, U4.25 (GPA4)
/~RD: J1.25, U2.18 (PD4)
/~RST: J1.20, U4.22 (GPA1)
/~SDCS: J7.13, J7.16, R2.1, U1.5 (O1)
/~WAIT: D3.2 (A), J2.9, U2.2 (PB1)
/~WR: J1.24, U2.19 (PD5)
GND: C1.2, C2.2, C3.2, C4.2, C5.2, C6.2, J1.17, J2.1, J3.6, J5.1, J5.2, J7.1, J7.8, SW1.1, SW2.1, U1.1 (E), U1.8 (GND), U2.11 (GND), U2.31 (GND), U3.7 (GND), U4.10 (GND), U4.15 (A0), U4.16 (A1), U4.17 (A2)
unnamed: C2.1, U2.13 (XTAL1), Y1.1
unnamed: C3.1, U2.12 (XTAL2), Y1.2
unnamed: C7.2, J5.11
unnamed: D1.2 (A), SW2.2, U4.26 (GPA5)
unnamed: D2.1 (K), R2.2
unnamed: D3.1 (K), U3.8
unnamed: J4.3, U1.12 (O0)
unnamed: J4.5, U1.11 (O1)
unnamed: J4.7, U1.10 (O2)
unnamed: J4.9, U1.9 (O3)
unnamed: J4.2, J4.4, J4.6, J4.8, J4.10, J4.12, U3.5
unnamed: J5.7, R4.1
unnamed: J5.8, R6.2
unnamed: J5.9, R3.1
unnamed: J5.10, R5.2
unnamed: U3.6, U3.10
unnamed: U3.4, U3.11
unnamed: U3.3, U3.12
VCC: C1.1, C4.1, C5.1, C6.1, D2.2 (A), J1.18, J2.2, J3.2, J4.1, J6.1, J7.3, J7.4, R1.1, U1.16 (VCC), U2.10 (VCC), U2.30 (AVCC), U2.32 (AREF), U3.14 (VCC), U4.9 (VCC)

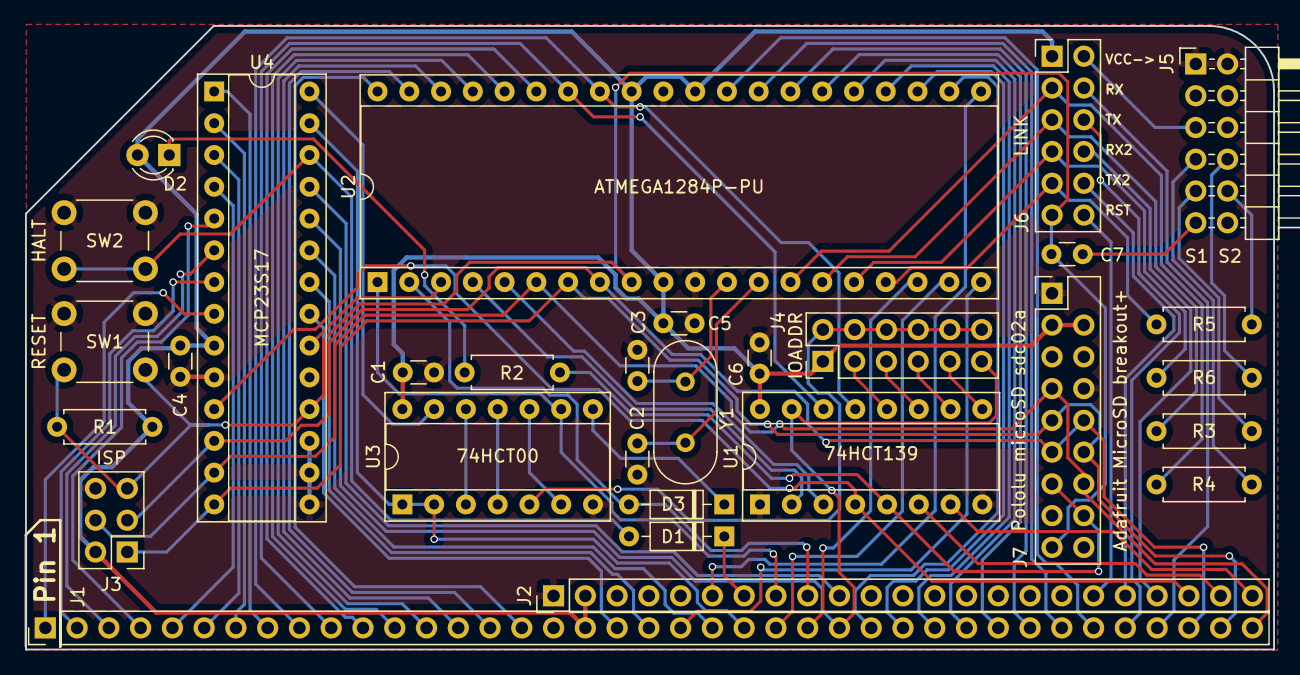
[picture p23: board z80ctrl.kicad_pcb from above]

Board: 2 copper layers, 99.8 x 49.9 mm, 30 parts (0 on the bottom side), 79 nets.

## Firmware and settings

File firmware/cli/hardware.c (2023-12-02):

/* z80ctrl (https://github.com/jblang/z80ctrl)
 * Copyright 2018-2023 J.B. Langston
 *
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
 * THE SOFTWARE IS PROVIDED "AS IS", WITHOUT WARRANTY OF ANY KIND, EXPRESS OR
 * IMPLIED, INCLUDING BUT NOT LIMITED TO THE WARRANTIES OF MERCHANTABILITY,
 * FITNESS FOR A PARTICULAR PURPOSE AND NONINFRINGEMENT. IN NO EVENT SHALL THE
 * AUTHORS OR COPYRIGHT HOLDERS BE LIABLE FOR ANY CLAIM, DAMAGES OR OTHER
 * LIABILITY, WHETHER IN AN ACTION OF CONTRACT, TORT OR OTHERWISE, ARISING
 * FROM, OUT OF OR IN CONNECTION WITH THE SOFTWARE OR THE USE OR OTHER
 * DEALINGS IN THE SOFTWARE.
 */

/**
 * @file hardware.c commands for interacting with hardware
 */

#include <stdint.h>
#include <stdio.h>
#include <stdlib.h>
#include <time.h>

#include "hardware/mcp23s17.h"
#include "hardware/rtc.h"
#include "hardware/uart.h"

#include "util/pgmspace.h"

/**
 * Set the baud rate for the UART
 */
void cli_baud(int argc, char* argv[])
{
    if (argc != 3) {
        printf_P(PSTR("usage: baud <uart> <baud>\n"));
        return;
    }
    uint8_t uart = strtoul(argv[1], NULL, 10) & 1;
    uint32_t requested = strtoul(argv[2], NULL, 10);
    uint16_t ubrr = 0;
    uint32_t actual = 0;
    // Find closest possible actual baud rate
    for (;;) {
        actual = (uint32_t)F_CPU / ((uint32_t)16 * ((uint32_t)ubrr + (uint32_t)1));
        if (actual <= requested)
            break;
        ubrr++;
        // stop if we have maxed out UBRR
        if (ubrr == 0)
            break;
    }
    printf_P(PSTR("UART %u: requested: %lu, actual: %lu\n"), uart, requested, actual);
    uart_flush();
    uart_init(uart, ubrr);
}

#ifdef USE_RTC
/**
 * Display or set the date on the RTC
 */
void cli_date(int argc, char* argv[])
{
    struct tm date;
    char datestr[30];
    if (argc < 8) {
        rtc_get_date(&date);
        printf_P(PSTR("The time is %d:%02d:%02d on %d/%d/%02d\n"), date.tm_hour, date.tm_min, date.tm_sec, date.tm_mon, date.tm_mday, date.tm_year);
        printf_P(PSTR("usage: date <yy mm dd wd hh mm ss>\n"));
        return;
    }

    date.tm_year = strtoul(argv[1], NULL, 10);
    date.tm_mon = strtoul(argv[2], NULL, 10);
    date.tm_mday = strtoul(argv[3], NULL, 10);
    date.tm_wday = strtoul(argv[4], NULL, 10);
    date.tm_hour = strtoul(argv[5], NULL, 10);
    date.tm_min = strtoul(argv[6], NULL, 10);
    date.tm_sec = strtoul(argv[7], NULL, 10);
    rtc_set_date(&date);
}
#endif

void cli_ioxread(int argc, char* argv[])
{
    if (argc != 3) {
        printf_P(PSTR("usage: ioxread <addr> <reg>\n"));
        return;
    }
    uint8_t addr = strtoul(argv[1], NULL, 16) & 0x7;
    if (addr < 1 || addr > 7) {
        printf_P(PSTR("invalid address. must be between 1 and 7\n"));
        return;
    }
    uint8_t reg = strtoul(argv[2], NULL, 16) & 0x1F;
    uint8_t value = iox_read(addr, reg);
    printf_P(PSTR("Read %02x from io expander %x register %02x\n"), value, addr, reg);
}

void cli_ioxwrite(int argc, char* argv[])
{
    if (argc != 4) {
        printf_P(PSTR("usage: ioxwrite <addr> <reg> <value>\n"));
        return;
    }
    uint8_t addr = strtoul(argv[1], NULL, 16) & 0x7;
    if (addr < 1 || addr > 7) {
        printf_P(PSTR("invalid address. must be between 1 and 7\n"));
        return;
    }
    uint8_t reg = strtoul(argv[2], NULL, 16) & 0x1F;
    uint8_t value = strtoul(argv[3], NULL, 16);
    iox_write(addr, reg, value);
}

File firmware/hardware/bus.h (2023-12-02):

/* z80ctrl (https://github.com/jblang/z80ctrl)
 * Copyright 2018-2023 J.B. Langston
 *
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
 * THE SOFTWARE IS PROVIDED "AS IS", WITHOUT WARRANTY OF ANY KIND, EXPRESS OR
 * IMPLIED, INCLUDING BUT NOT LIMITED TO THE WARRANTIES OF MERCHANTABILITY,
 * FITNESS FOR A PARTICULAR PURPOSE AND NONINFRINGEMENT. IN NO EVENT SHALL THE
 * AUTHORS OR COPYRIGHT HOLDERS BE LIABLE FOR ANY CLAIM, DAMAGES OR OTHER
 * LIABILITY, WHETHER IN AN ACTION OF CONTRACT, TORT OR OTHERWISE, ARISING
 * FROM, OUT OF OR IN CONNECTION WITH THE SOFTWARE OR THE USE OR OTHER
 * DEALINGS IN THE SOFTWARE.
 */

/**
 * @file bus.h Low-level control of the Z80 bus
 */

#ifndef HARDWARE_BUS_H
#define HARDWARE_BUS_H

#include <avr/io.h>

#include "mcp23s17.h"

/**
 * Address Bus
 */

#define ADDRLO_DDR DDRA
#define ADDRLO_PORT PORTA
#define ADDRLO_PIN PINA

#if (BOARD_REV == 3 || BOARD_REV == 4)
#define ADDRHI_IODIR IODIRA
#define ADDRHI_GPPU GPPUA
#define ADDRHI_GPIO GPIOA
#elif (BOARD_REV == 5 || BOARD_REV == 6)
#define ADDRHI_IODIR IODIRB
#define ADDRHI_GPPU GPPUB
#define ADDRHI_GPIO GPIOB
#else
#error "Unsupported board revision. Set BOARD_REV in your Makefile to match your board revision."
#endif

#define ADDR_INPUT (ADDRLO_DDR = 0x00, iox0_write(ADDRHI_IODIR, 0xFF))
#define ADDR_OUTPUT (ADDRLO_DDR = 0xFF, iox0_write(ADDRHI_IODIR, 0x00))

#define GET_ADDRLO ADDRLO_PIN
#define SET_ADDRLO(addr) ADDRLO_PORT = (addr)

#define GET_ADDRHI iox0_read(ADDRHI_GPIO)
#define SET_ADDRHI(addr) iox0_write(ADDRHI_GPIO, (addr))

#define GET_ADDR (GET_ADDRLO | (GET_ADDRHI << 8))
#define SET_ADDR(addr) (SET_ADDRLO((addr) & 0xFF), SET_ADDRHI((addr) >> 8))

/**
 * Data Bus
 */

#define DATA_DDR DDRC
#define DATA_PORT PORTC
#define DATA_PIN PINC

#define DATA_INPUT DATA_DDR = 0x00
#define DATA_OUTPUT DATA_DDR = 0xFF
#define GET_DATA DATA_PIN
#define SET_DATA(data) DATA_PORT = (data)

/**
 * PORTB flags
 */

#define BUSRQ (1 << 0)

#define GET_BUSRQ (PINB & BUSRQ)
#define BUSRQ_STATUS (status.flags & BUSRQ)
#define BUSRQ_HI PORTB |= BUSRQ
#define BUSRQ_LO PORTB &= ~BUSRQ

#define CTRLB_MASK 0x0F
#define CTRLB_OUTPUT_INIT DDRB |= BUSRQ

#if (BOARD_REV == 3 || BOARD_REV == 4)
#define IORQ (1 << 1)
#define MREQ (1 << 2)

#define GET_MREQ (PINB & MREQ)
#define MREQ_STATUS (status.flags & MREQ)
#define MREQ_HI PORTB |= MREQ
#define MREQ_LO PORTB &= ~MREQ

#define GET_IORQ (PINB & IORQ)
#define IORQ_STATUS (status.flags & IORQ)
#define IORQ_HI PORTB |= IORQ
#define IORQ_LO PORTB &= ~IORQ

#define IOMR_HI PORTB |= (IORQ | MREQ)
#define IOMR_OUTPUT DDRB |= (IORQ | MREQ)
#define IOMR_INPUT DDRB &= ~(IORQ | MREQ)

#define GET_WAIT (GET_IORQ || !GET_BUSRQ)
#define WAIT_STATUS (IORQ_STATUS || !BUSRQ_STATUS)

#define GET_IOXINT 0
#define IOXINT_STATUS 0
#elif (BOARD_REV == 5 || BOARD_REV == 6)
#define WAIT (1 << 1)
#define IOXINT (1 << 2)

#define GET_WAIT (PINB & WAIT)
#define WAIT_STATUS (status.flags & WAIT)

#define GET_IOXINT (PINB & IOXINT)
#define IOXINT_STATUS (status.flags & IOXINT)
#endif

/**
 * PORTD Flags
 */

#define RD (1 << 4)
#define WR (1 << 5)
#define CLK (1 << 6)
#define BUSACK (1 << 7)

#define GET_RD (PIND & RD)
#define RD_STATUS (status.flags & RD)
#define RD_HI PORTD |= RD
#define RD_LO PORTD &= ~RD

#define GET_WR (PIND & WR)
#define WR_STATUS (status.flags & WR)
#define WR_HI PORTD |= WR
#define WR_LO PORTD &= ~WR

#define RDWR_INPUT DDRD &= ~(RD | WR)
#define RDWR_OUTPUT DDRD |= (RD | WR)
#define RDWR_HI PORTD |= (RD | WR)

#define GET_CLK (PIND & CLK)
#define CLK_STATUS (status.flags & CLK)
#define CLK_HI PORTD |= CLK
#define CLK_LO PORTD &= ~CLK
#define CLK_TOGGLE PIND |= CLK

#define GET_BUSACK (PIND & BUSACK)
#define BUSACK_STATUS (status.flags & BUSACK)

#define CTRLD_MASK 0xF0
#define CTRLD_OUTPUT_INIT DDRD |= CLK

/**
 * IOX flags
 */

#if (BOARD_REV == 3 || BOARD_REV == 4)
#define CTRLX_IODIR IODIRB
#define CTRLX_GPPU GPPUB
#define CTRLX_GPIO GPIOB
#define CTRLX_INTCON INTCONB
#define CTRLX_DEFVAL DEFVALB
#define CTRLX_GPINTEN GPINTENB
#define CTRLX_INTCAP INTCAPB
#define RFSH (1 << 1)
#define RESET (1 << 2)
#define INTERRUPT (1 << 3)
#define M1 (1 << 4)
#define HALT (1 << 5)
#define NMI (1 << 7)

#define CTRLX_OUTPUT_INIT // No-op

#define GET_RFSH (iox0_read(CTRLX_GPIO) & RFSH)
#define RFSH_STATUS (status.xflags & RFSH)

#elif (BOARD_REV == 5 || BOARD_REV == 6)
#define CTRLX_IODIR IODIRA
#define CTRLX_GPPU GPPUA
#define CTRLX_GPIO GPIOA
#define CTRLX_INTCON INTCONA
#define CTRLX_DEFVAL DEFVALA
#define CTRLX_GPINTEN GPINTENA
#define CTRLX_INTCAP INTCAPA
#define M1 (1 << 0)
#define RESET (1 << 1)
#define INTERRUPT (1 << 2)
#define IORQ (1 << 3)
#define NMI (1 << 4)
#define HALT (1 << 5)
#define MREQ (1 << 6)
#define MWAIT (1 << 7)

#define CTRLX_OUTPUT_INIT iox0_clear(CTRLX_IODIR, MWAIT)

#define GET_MWAIT (iox0_read(CTRLX_GPIO) & MWAIT)
#define MWAIT_STATUS (status.xflags & MWAIT)
#define MWAIT_LO iox0_clear(CTRLX_GPIO, MWAIT)
#define MWAIT_HI iox0_set(CTRLX_GPIO, MWAIT)

#define GET_MREQ (iox0_read(CTRLX_GPIO) & MREQ)
#define MREQ_STATUS (status.xflags & MREQ)
#define MREQ_LO iox0_clear(CTRLX_GPIO, MREQ)
#define MREQ_HI iox0_set(CTRLX_GPIO, MREQ)

#define GET_IORQ (iox0_read(CTRLX_GPIO) & IORQ)
#define IORQ_STATUS (status.xflags & IORQ)
#define IORQ_LO iox0_clear(CTRLX_GPIO, IORQ)
#define IORQ_HI iox0_set(CTRLX_GPIO, IORQ)

#define IOMR_INPUT iox0_set(CTRLX_IODIR, IORQ | MREQ)
#define IOMR_OUTPUT iox0_clear(CTRLX_IODIR, IORQ | MREQ)
#define IOMR_HI iox0_set(CTRLX_GPIO, IORQ | MREQ)

#define GET_RFSH (GET_MREQ || !(GET_RD && GET_WR))
#define RFSH_STATUS (MREQ_STATUS || !(RD_STATUS && WR_STATUS))
#endif

#define GET_M1 (iox0_read(CTRLX_GPIO) & M1)
#define M1_STATUS (status.xflags & M1)

#define GET_HALT (iox0_read(CTRLX_GPIO) & HALT)
#define HALT_STATUS (status.xflags & HALT)

// RESET, INT, and NMI behave like an open drain. It is only an output when it is low.
#define GET_RESET (iox0_read(CTRLX_GPIO) & RESET)
#define RESET_STATUS (status.xflags & RESET)
#define RESET_OUTPUT iox0_clear(CTRLX_IODIR, RESET)
#define RESET_INPUT iox0_set(CTRLX_IODIR, RESET)

#define GET_INT (iox0_read(CTRLX_GPIO) & INTERRUPT)
#define INT_STATUS (status.xflags & INTERRUPT)
#define INT_OUTPUT iox0_clear(CTRLX_IODIR, INTERRUPT)
#define INT_INPUT iox0_set(CTRLX_IODIR, INTERRUPT)

#define GET_NMI (iox0_read(CTRLX_GPIO) & NMI)
#define NMI_STATUS (status.xflags & NMI)
#define NMI_OUTPUT iox0_clear(CTRLX_IODIR, NMI)
#define NMI_INPUT iox0_set(CTRLX_IODIR, NMI)

#define CTRLX_PULLUP_INIT iox0_set(CTRLX_GPPU, (HALT | RESET | INTERRUPT | NMI))

/**
 * Complete bus status all in one place
 */
typedef struct {
    uint8_t flags;
    uint8_t xflags;
    uint16_t addr;
    uint8_t data;
} bus_stat;

extern uint32_t base_addr;

void set_clkdiv(uint8_t div);
uint8_t get_clkdiv(void);
void clk_cycle(uint8_t cycles);
void clk_run(void);
void clk_stop(void);

uint8_t bus_request(void);
uint8_t bus_release(void);
void bus_init(void);

bus_stat bus_status(void);
bus_stat bus_status_fast(void);
void bus_log(bus_stat status);
#endif

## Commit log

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2018-01-09 Change from inline functions to macros for low level bus ops Change from interrupt to polling for IORQ Increase clock to 10MHz Add memory verification step to startup process Fixed negative logic bug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
    [bus.h]
2018-01-10 Update hello world to use Altair-compatible UART ports
2018-01-10 Make UART ports compatible with Altair. Load turnkey monitor at startup.
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2018-01-12 Rename INT to INTERRUPT to avoid conflict with fatfs
    [bus.h]
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2018-01-13 Fix ALTMON sources to assemble with asm8080
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2018-01-13 Add bank command Switch from sscanf to strtol Switch order of argv and argc to match c convention
2018-01-19 Switch to using start/end instead of start/length for fill and dump; move fill logic to memory.c
2018-01-21 First crack at real-time disassembly
    [z80.c]
2018-01-26 Adding kicad schema and board layout
    [z80ctrl.kicad_pcb, z80ctrl.sch]
2018-01-27 Fix power-up reset hang bug
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2018-02-04 Updated schematic
    [z80ctrl.kicad_pcb, z80ctrl.sch]
2018-02-11 Reroute to reduce via count
    [z80ctrl.kicad_pcb, z80ctrl.sch]
2018-02-11 Add jumpers to disconnect VCC net from serial connector
    [z80ctrl.kicad_pcb, z80ctrl.sch]
2018-02-14 Tweak routes
    [z80ctrl.kicad_pcb, z80ctrl.sch]
2018-02-15 Add diode to prevent reset button from short circuiting
    [z80ctrl.kicad_pcb, z80ctrl.sch]
2018-02-16 Final tweaks before submitting REV1
    [z80ctrl.kicad_pcb]
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2018-04-20 Fix code to match SPIA0/SPIA1 cross-wiring error made on REV1 board
2018-05-05 Fix capacitor values on schematic
    [z80ctrl.sch]
2018-05-05 Reroute SPI tracks, cleanup track layout
    [z80ctrl.kicad_pcb]
2018-05-05 Reroute DTR trace away from board edge to avoid manufacturing defects
    [z80ctrl.kicad_pcb]
2018-05-05 First pass at operand decoding in debugger (may still be some bugs)
    [z80.c]
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2018-05-10 OCD tweaks
    [z80ctrl.kicad_pcb]
2018-05-10 More breakpoint/trace bugfixes
2018-05-10 Add ISP header to REV2
    [z80ctrl.kicad_pcb, z80ctrl.sch]
2018-05-16 Fix needing to double-step when breakpoints are enabled
    [z80.c]
2018-05-16 Add IX/IY mode and fix disassembly bugs
    [disasm.c]
2018-05-18 Add BOM part numbers
    [z80ctrl.sch, z80ctrl_bom_REV2.csv]
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2018-05-19 Fix UART flush
2018-05-19 Switch to C99 mode, fix compiler warnings
    [spi.h]
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2018-05-21 Fix bugs in IORQ and MREQ logging
    [z80.c]
2018-05-22 Fix some breakpoint bugs
    [z80.c]
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2018-05-24 First crack at DMA disk transfers; still buggy, no write support
2018-05-25 Tweaks to disk emulation; fixed sectors per track
2018-05-25 Fix issues with DMA disk access
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2018-05-30 REV3 board: Add Adafruit SD header; swap BUSRQ and M1; Replace RFSH with SD enable
    [z80ctrl.kicad_pcb, z80ctrl.sch]
2018-05-30 Update pin assignments for REV3; fix bugs that were revealed
    [bus.h, spi.h, z80.c]
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2018-06-02 Add initial support for paged memory (still some bugs)
    [bus.h, z80.c]
2018-06-09 More tweaks for REV3
    [z80ctrl.kicad_pcb, z80ctrl.sch]
2018-06-15 Generate REV3 files
    [z80ctrl.kicad_pcb]
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2018-10-25 Added io expander board
    [z80ctrl-iox.kicad_pcb, z80ctrl-iox.sch]
2018-10-25 Update for KiCad 5.0
    [z80ctrl.kicad_pcb, z80ctrl.sch]
2018-10-26 Add RTC
    [z80ctrl-iox.kicad_pcb, z80ctrl-iox.sch]
2018-10-28 Make initial changes for REV4
    [z80ctrl.kicad_pcb, z80ctrl.sch]
2018-10-28 Remove extra text from IOX module
    [z80ctrl-iox.kicad_pcb]
2018-11-02 Final tweaks to I/O expander
    [z80ctrl-iox.kicad_pcb, z80ctrl-iox.sch]
2018-11-02 REV4 Tweaks
    [z80ctrl.kicad_pcb, z80ctrl.sch]
2018-11-14 Prepare for REV2 of IOX board
    [z80ctrl-iox.kicad_pcb, z80ctrl-iox.sch]
2018-11-14 Update silkscreen for REV2
    [z80ctrl-iox.kicad_pcb]
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2018-11-22 Fix 24 hour RTC bug
    [rtc.c]
2018-11-22 Add KiCad temp files to .gitignore and add missing KiCad files to repo
2018-11-25 Make RESET behave like open collector
    [bus.h]
2018-11-25 Mute SN76489 during reset
    [z80.c]
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2018-12-16 Fix search and replace screwup
2018-12-16 Update silkscreen
    [z80ctrl.kicad_pcb]
2018-12-22 added REV4 BOM
    [z80ctrl_bom_REV4.csv]
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2019-01-12 Fix revision on schematic
    [z80ctrl.sch]
2019-01-12 Update revision in schematic
    [z80ctrl-iox.sch]
2019-01-26 Updates for REV5
    [z80ctrl.kicad_pcb, z80ctrl.sch]
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2019-02-02 Fix masks for bus flags
    [bus.h]
2019-02-03 REV5 tweaks
    [z80ctrl.kicad_pcb, z80ctrl.sch]
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2019-02-08 Add legend for LINK header to back silkscreen
    [z80ctrl.kicad_pcb]
2019-02-08 Fix breaks in groundplane
    [z80ctrl.kicad_pcb]
2019-02-12 Fix us/ms calculation from timer ticks
2019-07-28 Add era and cd commands; add hidden commands (not shown in help)
    [z80ctrl.kicad_pcb, z80ctrl.sch]
2019-07-30 Add halt via keyboard shortcut
    [z80.c]
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2019-12-21 Fix compilation errors for memory paging
    [bus.h]
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2020-02-15 Clean up terminal code; fix bugs
    [uart.c]
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2020-07-17 Fix memory paging during reset
    [z80.c]
2020-07-18 Release bus before resetting to fix BDOS emulation issues
    [z80.c]
2020-07-18 Add missing ifdefs to device definitions
2020-07-19 Skip unnecessary bus handoff for DMA functions
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2020-09-01 Add Z80/RAM/RTC board
    [z80ram.kicad_pcb, z80ram.sch]
2020-09-01 Add REV5 hardware changes
    [z80ctrl.kicad_pcb, z80ctrl.sch]
2020-09-03 Add pullup resistors on z80ram board
    [z80ram.kicad_pcb, z80ram.sch]
2020-09-13 Switch to same capacitor footprint as z80ctrl board
    [z80ram.kicad_pcb, z80ram.sch]
2020-09-13 Gerber tweaks
    [z80ctrl.kicad_pcb, z80ram.kicad_pcb]
2020-09-19 Fix address decoding, minor REV2 tweaks
    [z80ram.kicad_pcb, z80ram.sch]
2020-09-20 Fix VCC1/VCC2 mixup on RTC, better layout for RTC crystal
    [z80ram.kicad_pcb, z80ram.sch]
2020-09-23 Make REV6 hardware changes
    [z80ctrl.kicad_pcb, z80ctrl.sch]
2020-09-26 Fix tactile button footprints
    [z80ctrl.kicad_pcb, z80ctrl.sch]
2020-09-26 Update serial port labels
    [z80ctrl.kicad_pcb]
2020-09-27 Final REV6 tweaks
    [z80ctrl.kicad_pcb]
2020-09-27 RAM/CPU REV2 final tweaks
    [z80ram.kicad_pcb]
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2020-10-13 Update REV6 BOM
    [z80ctrl.sch, z80ctrl_bom_REV6.csv]
2020-10-13 Fix mouser part number on REV6 bom
    [z80ctrl.sch, z80ctrl_bom_REV6.csv]
2020-10-13 Fix 74HCT00 datasheet on REV6 bom
    [z80ctrl.sch, z80ctrl_bom_REV6.csv]
2020-10-14 Add BOM for z80ram REV2
    [z80ram.sch, z80ram_bom_REV2.csv]
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2020-11-22 Oops, revert experimental changes to real REV6 schematic
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2022-03-05 added fix for AdaFruit SD Card module
    [spi.c, spi.h]
2022-10-22 Upgrade Kicad projects to v6
    [z80ctrl-iox.kicad_pcb, z80ctrl-iox.kicad_sch, z80ctrl-iox.sch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]
2023-07-22 Fix halt behavior on REV5/REV6
    [bus.h, z80.c]
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2023-11-29 Preliminary design for new motherboard with AVR128DB64
    [avr128db64.kicad_pcb, avr128db64.kicad_sch]
2023-12-07 Rework cli command definition into single string
    [io.c, z80.c]
2023-12-10 Further updates to PCB
    [avr128db64.kicad_pcb, avr128db64.kicad_sch]
2023-12-11 Additional traces
    [avr128db64.kicad_pcb, avr128db64.kicad_sch]
2023-12-12 Finish routing all signals and fix DRC errors
    [avr128db64.kicad_pcb, avr128db64.kicad_sch]
2023-12-13 Move to hybrid layout: TH RAM and Logic ICs
    [avr128db64.kicad_pcb, avr128db64.kicad_sch]
2023-12-14 Finish layout for hybrid design
    [avr128db64.kicad_pcb, avr128db64.kicad_sch]
2023-12-15 Finishing up...
    [avr128db64.kicad_pcb, z80ctrlng.kicad_pcb, z80ctrlng.kicad_sch]
2023-12-17 Rework bus links using jumpers instead of dip switches; add labels
    [z80ctrlng.kicad_pcb, z80ctrlng.kicad_sch]
2023-12-19 More cleanup, fixing errors
    [z80ctrlng.kicad_pcb, z80ctrlng.kicad_sch]
2023-12-20 Rework to make room for clock jumper
    [z80ctrlng.kicad_pcb, z80ctrlng.kicad_sch]
2024-01-06 Switch to RCBus-80 footprints, JLCPCB preferred components
    [peripherals.kicad_sch, z80blinken.kicad_pcb, z80blinken.kicad_sch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]
2024-01-08 Final touches... I hope
    [peripherals.kicad_sch, z80ctrlng.kicad_pcb, z80ctrlng.kicad_sch]
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2024-01-09 Fixing mistakes on RX/TX, better isolation for RTC
    [peripherals.kicad_sch, z80ctrlng.kicad_pcb, z80ctrlng.kicad_sch]
2024-01-12 More final touches o.O
    [peripherals.kicad_sch, z80ctrlng.kicad_pcb, z80ctrlng.kicad_sch]
2024-01-18 Muntz unnecessary jumpers/switches; add SerialUDPI programmer; cleanup layout
    [peripherals.kicad_sch, z80ctrlng.kicad_pcb, z80ctrlng.kicad_sch]
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2024-01-20 Rearrange to make fast 3.3V buses shorter
    [peripherals.kicad_sch, z80ctrlng.kicad_pcb, z80ctrlng.kicad_sch]
2024-01-20 Copper pour, via stitching, silkscreen
    [z80ctrlng.kicad_pcb]
2024-01-21 Updating silkscreen
    [peripherals.kicad_sch, z80ctrlng.kicad_pcb, z80ctrlng.kicad_sch]
2024-01-21 Remove test points; finish silkscreen
    [z80blinken.kicad_pcb, z80blinken.kicad_sch]
2024-01-21 Fix nested directory
    [z80blinken.kicad_pcb, z80blinken.kicad_sch]
2024-01-24 Misc tweaks to boards
    [peripherals.kicad_sch, z80blinken.kicad_pcb, z80blinken.kicad_sch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]
2024-01-25 Put resistor before switch to avoid parasitic powering of the board
    [peripherals.kicad_sch, z80ctrlng.kicad_pcb]
2024-01-26 Reorganize hardware directories
    [peripherals.kicad_sch, z80blinken.kicad_pcb, z80blinken.kicad_sch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]
2024-02-08 Get rid of serial bus links, make banking software controllable
    [peripherals.kicad_sch, z80ctrlng.kicad_pcb, z80ctrlng.kicad_sch]

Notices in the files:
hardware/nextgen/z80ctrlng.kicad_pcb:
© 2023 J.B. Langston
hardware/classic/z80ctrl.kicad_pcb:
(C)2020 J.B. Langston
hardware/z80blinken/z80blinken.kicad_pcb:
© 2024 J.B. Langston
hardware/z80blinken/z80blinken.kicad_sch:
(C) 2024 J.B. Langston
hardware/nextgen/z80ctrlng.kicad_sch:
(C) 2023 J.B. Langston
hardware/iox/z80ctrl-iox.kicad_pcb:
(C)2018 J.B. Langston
